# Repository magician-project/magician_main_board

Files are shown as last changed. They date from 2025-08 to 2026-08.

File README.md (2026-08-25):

# Magician Main Board for Sensing Robot

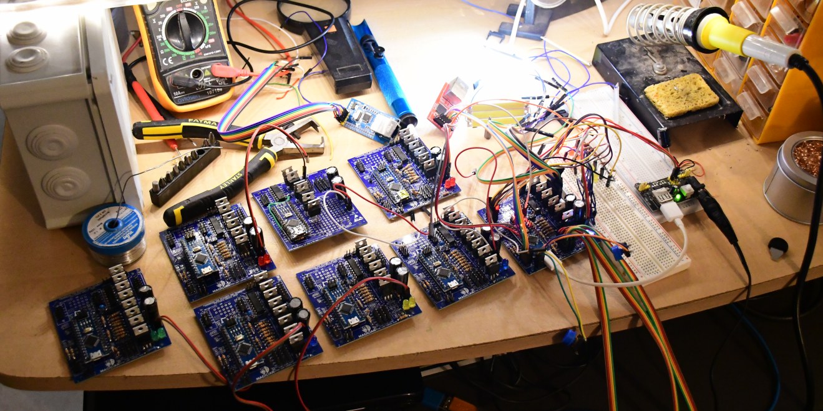
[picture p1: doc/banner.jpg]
8 Protype Assembled PCBs
 

This project implements a **multi-laser distance sensing and light control system** on an **Arduino Nano (ATmega328P)**. 

> This README documents the original [`src/kicad/v1`](src/kicad/v1/README.md) board and its Arduino Nano firmware. The current hardware revision is **MagicianCam4** ([`src/kicad/v4`](src/kicad/v4/README.md)), built around a Raspberry Pi Pico 2 with a VL53L5CX multizone ToF sensor; its firmware lives in [`src/pico2`](src/pico2/).

The software that drives this PCB (along with the Camera/ATI/Teensy) is the [Magician Grabber](https://github.com/magician-project/magician_grabber)

It integrates:

- **3x VL53L0X time-of-flight distance sensors** (over I²C, with unique addresses via XSHUT control) 
- **Up to 8 lights** controlled via direct GPIO or a **74HC595 shift register**
- **Extendable up to 64 lights** by daisy chaining more **74HC595 shift registers**
- **Ethernet W5100 support** (Telnet-style interface) 
- **Two analog input buttons** for manual interaction
- **Serial + Ethernet reporting** of sensor readings, light state, and button presses

The firmware cycles lights automatically, can react to distance sensor readings, and supports both **serial commands** and **Ethernet control**.

---

## Features

- 🔦 **3x VL53L0X** laser distance sensors on a shared I²C bus
- 💡 **6x-8x LED light outputs** (6x direct pin mode or 8x via 74HC595 shift register)
- 🌐 **Ethernet W5100 support** with telnet-style server on port `23`
- 🎛️ **Two analog buttons** (for annotations / input)
- ⚡ **Low-level SRAM monitoring** and reset recovery functions
- 🛠️ **Configurable light modes:**
  - Sequential cycling
  - Pulse mode
  - Sensor-based closest-light decision
  - Timed flashing

---

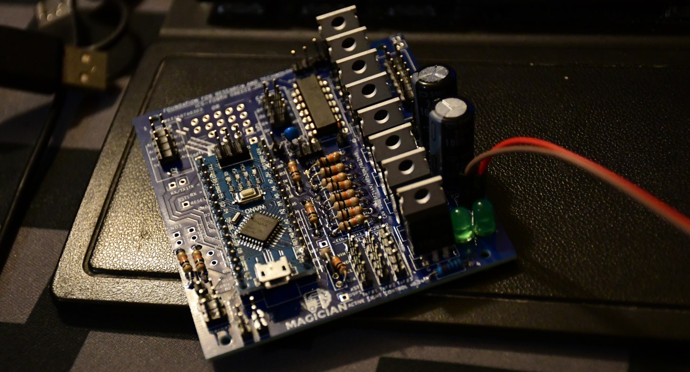
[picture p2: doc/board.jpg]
Magician Main Board close-up
 

## Setup

Important: Before connecting the board, [read the following guide](doc/connectors.md)!

## Hardware Components

- **Arduino Nano with USB-Micro port/ UNO (ATmega328P)**  
- **VL53L0X distance sensors** (x3)  
- **W5100 Ethernet module/shield**  
- **74HC595 shift register** (optional, for light control)  
- **6 LEDs or lights** (controlled by direct pins or shift register)  
- **2 push buttons** (wired to analog inputs `A6` and `A7`)  

### Pin Mapping

| Component | Pin(s) Used | Notes |
|---|---|---|
| I²C (VL53L0X) | A4 (SDA), A5 (SCL) | Shared bus |
| VL53L0X XSHUT (x3) | A0, A1, A2 | Controls sensor reset & addressing |
| Ethernet Reset | D9 | Shared with `I2C_EXTRA_PIN` |
| Direct Light Outputs | D3, D4, D5, D6, D7, D8 | Default pin mode |
| 74HC595 Latch (STCP) | D3 | Used if shift register enabled |
| 74HC595 Clock (SHCP) | D4 | 〃 |
| 74HC595 Data (DS) | D5 | 〃 |
| 74HC595 OE (Enable) | D2 | Active low |
| 74HC595 SRCLR (Clear) | A3 | Active low |
| Buttons | A6, A7 | Analog threshold detection |

---

## Software Setup

1. **Clone this repository** and the Pololu VL53L0X Arduino library:
   ```bash
   git clone https://github.com/YOUR_GITHUB_USERNAME/arduino-nano-vl53l0x-ethernet
   cd arduino-nano-vl53l0x-ethernet
   git clone https://github.com/pololu/vl53l0x-arduino
   cp vl53l0x-arduino/VL53L0X.cpp ./
   cp vl53l0x-arduino/VL53L0X.h ./

    Fix Arduino Nano memory constraints (important!):
    The VL53L0X library is heavy and may cause stack overflow resets.
    To prevent this, reduce the serial buffer sizes:

    Edit:

~/.arduino15/packages/arduino/hardware/avr/1.8.6/cores/arduino/HardwareSerial.h

Change:

    #define SERIAL_TX_BUFFER_SIZE 16
    #define SERIAL_RX_BUFFER_SIZE 8

    With this, the sketch fits:

        Program storage: ~66% used

        Dynamic memory: ~80% used (401 bytes free)

    Install dependencies in Arduino IDE:

        Wire.h (I²C, built-in)

        SPI.h (Ethernet, built-in)

        Ethernet.h (W5100)

    Upload the sketch to your Arduino Nano.

Serial & Ethernet Commands

To connect to Ethernet (assuming you are on the correct subnet)
```
telnet 192.168.137.64
```

To connect using USB/Serial (assuming you are connected over USB)
```
sudo apt install picocom
picocom -b 115200 /dev/ttyUSB0  --imap lfcrlf 
Ctrl + A + Q to exit
```

When connected via USB serial or Ethernet Telnet (port 23), you can control and query the system by supplying the following command bytes.

Command	Description:

| Command                     | Dangerous           | Description |
|-----------------------------|---------------------|-------|
| v              | No    | Print firmware version |
| h              | Yes   | Enable 74HC595 mode + auto light cycling |
| i              | Yes   | Disable 74HC595 (direct pin mode) |
| o              | Maybe | Continuous lights (disable pulsing) |
| p              | Maybe | Switch to pulsing of 500μs / Subsequent calls increase pulse length by 500µs |
| r              | No    | Reset light cycling |
| a              | No    | Enable sensor-based light selection |
| t              | No    | Enable custom cycling mode (mode 3) |
| y              | No    | Flash lights for 10s, then turn off |
| z              | No    | Turn off all lights and reset Arduino |
| 0-6            | Yes   | Manually activate light with number #N |
| +              | Yes   | Step to next light |
| f              | No    | Disable serial/Ethernet reporting |
| x              | No    | (Ethernet only) Print local IP + hardware status | 
| b              | No    | Make Analog Buttons have binary output  1/0 | 
| n              | No    | Make Analog Buttons have non-binary output  0-1024 | 

Commands marked as potentially dangerous directly alter light states that can be dangerous when
using a connected Camera Board that over volts lights. Please see [the setup guide](doc/connectors.md) to understand why. 

Data Reporting

When enabled, the Arduino periodically outputs status lines in CSV format:

<time_ms>,<button1>,<button2>,<distance1>,<distance2>,<distance3>,<light1>,<light2>,...<light6>

Example:

1050,0,1,523,812,1500,1,0,0,0,0,0

    time_ms – system uptime in ms

    button1/button2 – 0 or 1

    distanceN – measured distance in mm (F = failed, H = too high, 0 = inactive)

    lightN – 1 if active, 0 otherwise

Memory & Stability Notes

    Free SRAM is checked at startup; if less than 231 bytes are available, instability is expected.

    Use the reduced VL53L0X library and shrunk serial buffers for stability.

    A resetFunc() software reset is available to recover from low memory conditions.

Versioning

    Version: 0.26

    Major/minor defined in VERSION_MAJOR, VERSION_MINOR.

License

MIT License.
This project uses Pololu’s VL53L0X Arduino Library

Possible Future Improvements

    Add MQTT over Ethernet for IoT integration

    Support ESP32 (more SRAM, WiFi support, no buffer hacks needed)

    Add dynamic light patterns and user-configurable modes

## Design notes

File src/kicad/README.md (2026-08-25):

# KiCad Boards

This directory holds the KiCad projects for the Magician sensing PCBs, organized by hardware revision:

- [`v1/`](v1/README.md) — the original Magician Main Board (Arduino Nano, 3x VL53L0X, 74HC595 shift register). Superseded, kept for reference.
- [`v4/`](v4/README.md) — **MagicianCam4**, the current board (Raspberry Pi Pico 2, VL53L5CX multizone ToF sensor, MCP23018 I/O expander).

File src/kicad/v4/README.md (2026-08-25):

Designed by Giulio Vivo

# MagicianCam4

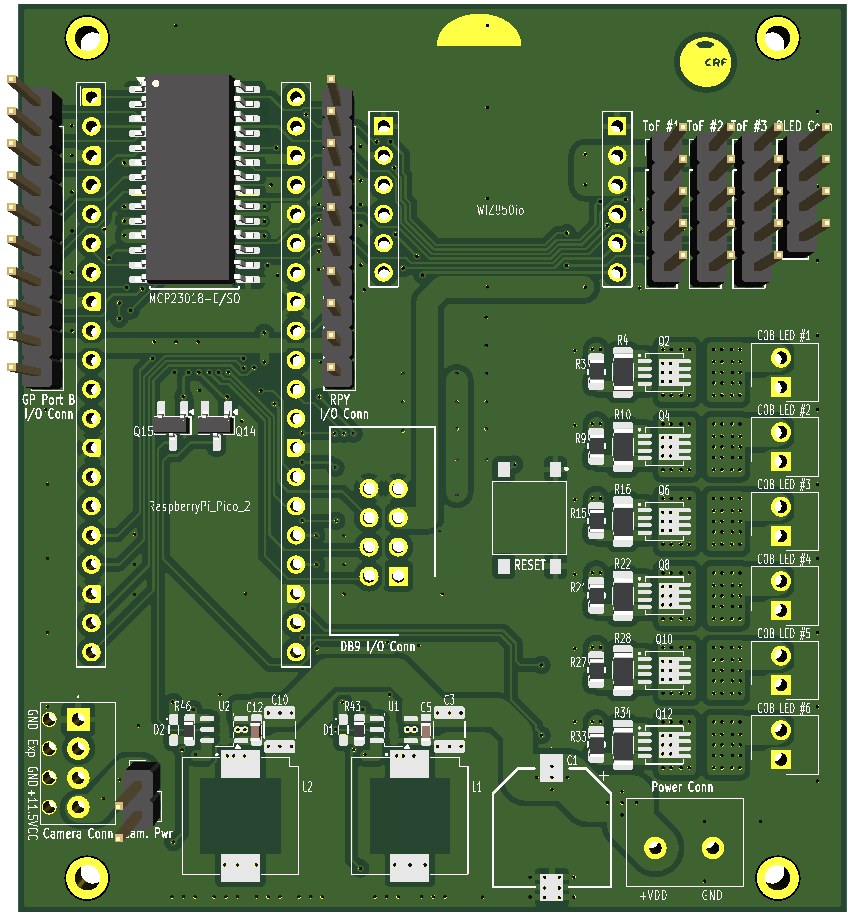
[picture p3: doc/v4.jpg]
MagicianCam4 board


Current revision of the Magician camera/sensing board, built around a **Raspberry Pi Pico 2 (RP2350)** instead of the Arduino Nano used in [`v1/`](../v1/README.md). Firmware lives in [`src/pico2/`](../../pico2/).

Main changes over v1:

- **VL53L5CX multizone ToF sensor** (8x8 = 64 distance zones) replacing the 3x VL53L0X single-zone sensors.
- **MCP23018 I²C I/O expander** for buttons and light control, replacing the 74HC595 shift register chain.
- Exposure-synced LED strobing with per-COB thermal budgeting, since the LED COBs are driven above their rated voltage and rely on strict pulse-width/duty-cycle limits to survive.
- Ethernet connectivity kept compatible with the camera board.

See the MAGICIAN D3.3 deliverable for the background on the sensor/board redesign (split Main + LED-strobe + Ethernet board layout, move from Arduino Mega/Nano to a smaller microcontroller footprint).

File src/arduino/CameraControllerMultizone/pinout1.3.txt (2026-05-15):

MCP23018
Port GPA0 is connected to Push Button 0 (PB0) Input
Port GPA1 is connected to Push Button 1 (PB1) Input
Port GPA2 is connected to ETH Reset pin (Output)
Port GPA3 is connected to XSHUT/laserSwitch port 1 (Output)
Port GPA4 is connected to XSHUT/laserSwitch port 2 (Output)
Port GPA5 is connected to XSHUT/laserSwitch port 3 (Output)
Port GPA6 is connected to A 5V Rail Enable pin (Output) (This will be inverted in 1.4)
Port GPA7 is connected to A 11.5V Rail Enable pin (Output) (This will be inverted in 1.4)

Port GPB0 is connected to nothing
Port GPB1 is connected to nothing 
Port GPB2 is connected to nothing 
Port GPB3 is connected to nothing
Port GPB4 is connected to nothing
Port GPB5 is connected to nothing
Port GPB6 is connected to nothing
Port GPB7 is connected to nothing

The initialization of the MCP23018 must be:
GPA0 is an input button
GPA1 is an input button
GPA2 is an output and should be High
GPA3,GPA4,GPA5 are outputs and should be High
GPA6 is an output should also be High 
GPA7 is an output should also be High

Ports GP4 and GP5 are connected to 3x ToF I2C sensors with initial address 0x52
The address of the MCP23018 is 0x20

The XCG-CP510 Camera is emitting an Active High exposure signal to Port GP2 of the Pico 2

The exposure signal enables a specific light.
Lights are connected in the following way.

Light 1 is connected to GP6
Light 2 is connected to GP7
Light 3 is connected to GP8
Light 4 is connected to GP9
Light 5 is connected to GP10
Light 6 is connected to GP11

The ethernet (W5500 USR-ES1)
is connected in the following way:
MISO is connected to GP16 of the Pico2
MOSI is connected to GP19 of the Pico2
SCCLK is connected to GP18 of the Pico2
SCN is connected to GP17 of the Pico2
INT is connected to GP22 of the Pico2
RST is connected to GPA2 of the MCP23018

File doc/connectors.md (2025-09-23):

# Magician Main Board Connections

Due to Magician being a research project (with a pending cascade round) and hardware being very difficult to upgrade there has been an effort to make the Magician Main board 
as expandable as possible, supporting a variety of operation modes using the same hardware.

When connecting the main board with the rest of the system, one must always keep in mind:
1) What is the LED COB lights rated voltage
2) Is the LED COB Light Output connected to the Main Board OR the Camera Board ?
3) What is the LED Voltage input and where it is connected (Main Board OR Camera Board) 

## Main Board and Camera Board Connections overview

There are 2x boards, the Main Board and the Camera Board.

The Main Board looks like this and features the following connectors.

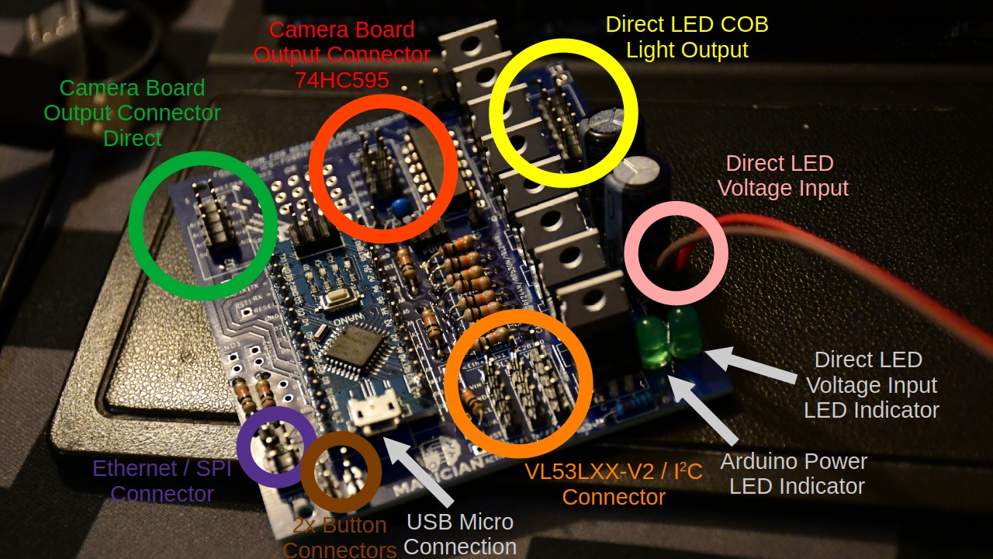
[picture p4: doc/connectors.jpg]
Magician Main Board PCB Connectors
 

The Camera Board looks like this and features the following connectors.

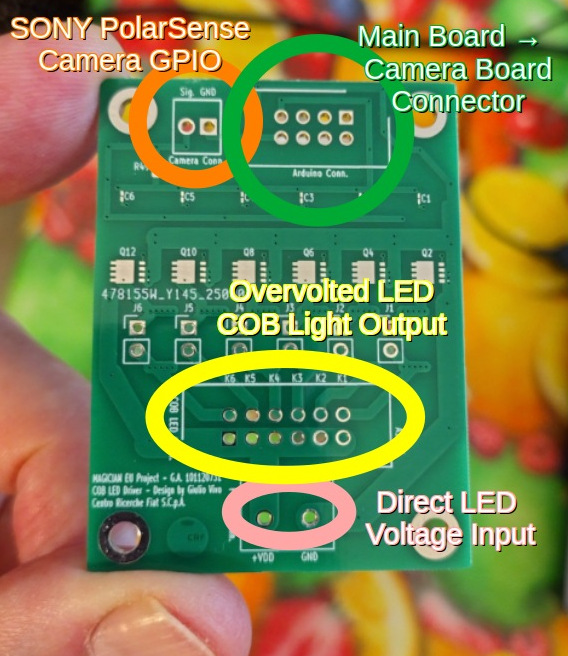
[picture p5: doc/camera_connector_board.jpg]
Magician Camera Board PCB Connectors
 

## Main Board Setup Scenarios

If you want to use regular non-overvolted lights and S/W Sync of lights to the Camera:

1) You do not need the Camera Board!
2) Connect the LED COBs to the (YELLOW Top Right) Direct LED COB Light output.
3) Connect the 3.3V LED COB input on the Direct LED Voltage Input (PINK color) of the Main Board
4) Start the Magician Mainboard by sending an "h" byte 

If you want to use LED overvolting and H/W Sync of lights to the Camera:

0) Since you are overvolting the LEDS past their factory specs you need to be VERY careful what you do!
1) Connect the Camera Board to the Magician Main Board using a cable that ties the GREEN headers ( on both images above ).
2) Connect the LED COBs to the Overvolted LED COB Light output of the Camera Board.
3) Connect the Overvolted LED COB input voltage on the Direct LED Voltage Input (PINK color) of the Camera Board
4) Start the Magician Mainboard by sending an "i" byte (this is the default behavior for safety reasons)

## Closer look on the PCBs and Diagrams

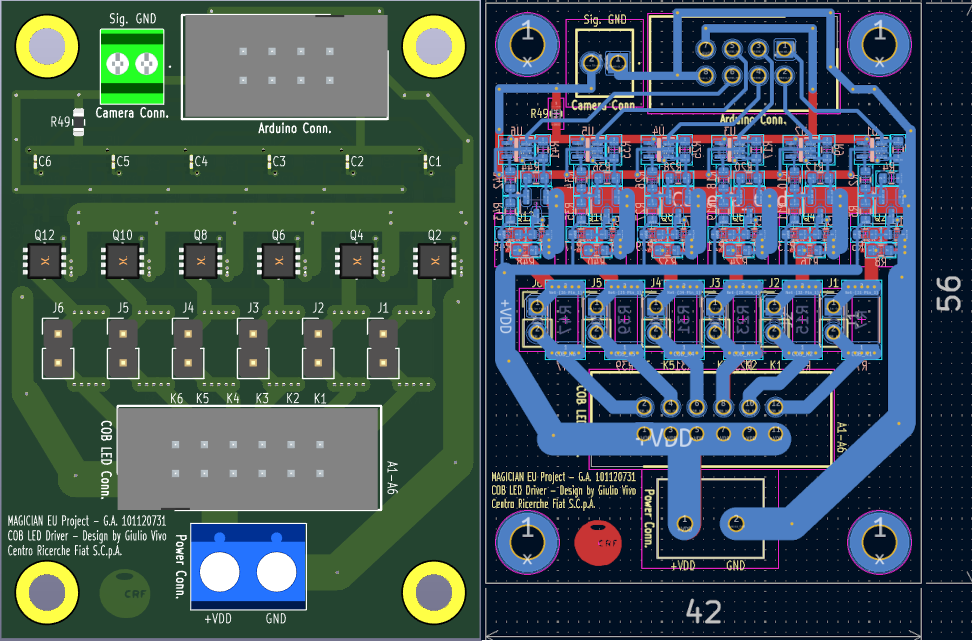
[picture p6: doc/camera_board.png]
Magician Camera Board PCB Connectors
 

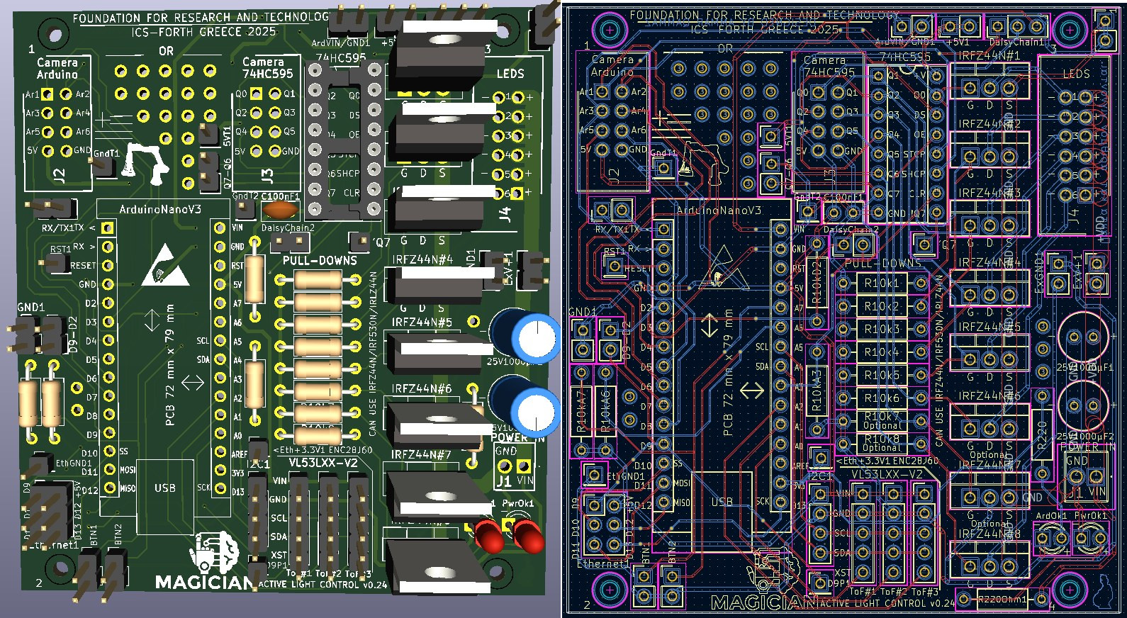
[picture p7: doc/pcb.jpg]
Magician Main Board close-up
 

## Connecting Ethernet support using a W5100

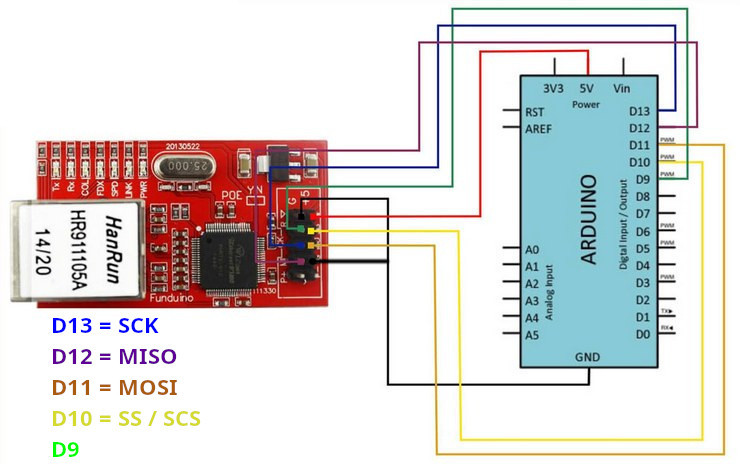
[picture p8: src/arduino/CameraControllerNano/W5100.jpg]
W5100 Ethernet SPI chip


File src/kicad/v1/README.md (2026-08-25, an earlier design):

# Magician Main Board (v1)

Original Magician Main Board PCB, designed around an **Arduino Nano (ATmega328P)** with 3x VL53L0X time-of-flight distance sensors and up to 64 lights driven through daisy-chained 74HC595 shift registers, per the [top-level README](../../../README.md).

This is the board described in the MAGICIAN D3.3 deliverable as replacing the earlier breadboard harness for the V2 camera sensor. It has been moved here from `src/kicad/` and superseded by [`v4/`](../v4/README.md) (MagicianCam4), which moves to a Raspberry Pi Pico 2 and a VL53L5CX multizone ToF sensor. Kept for reference and for any deployments still running this hardware revision.

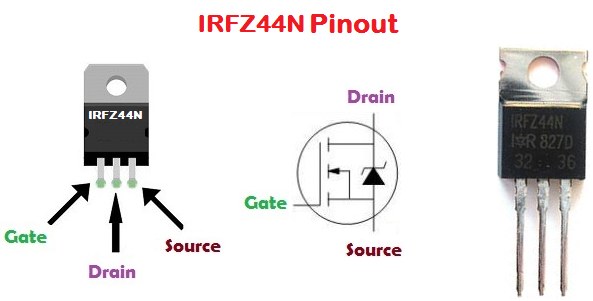
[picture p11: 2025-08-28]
src/arduino/CameraControllerNano/irfz44n.jpg

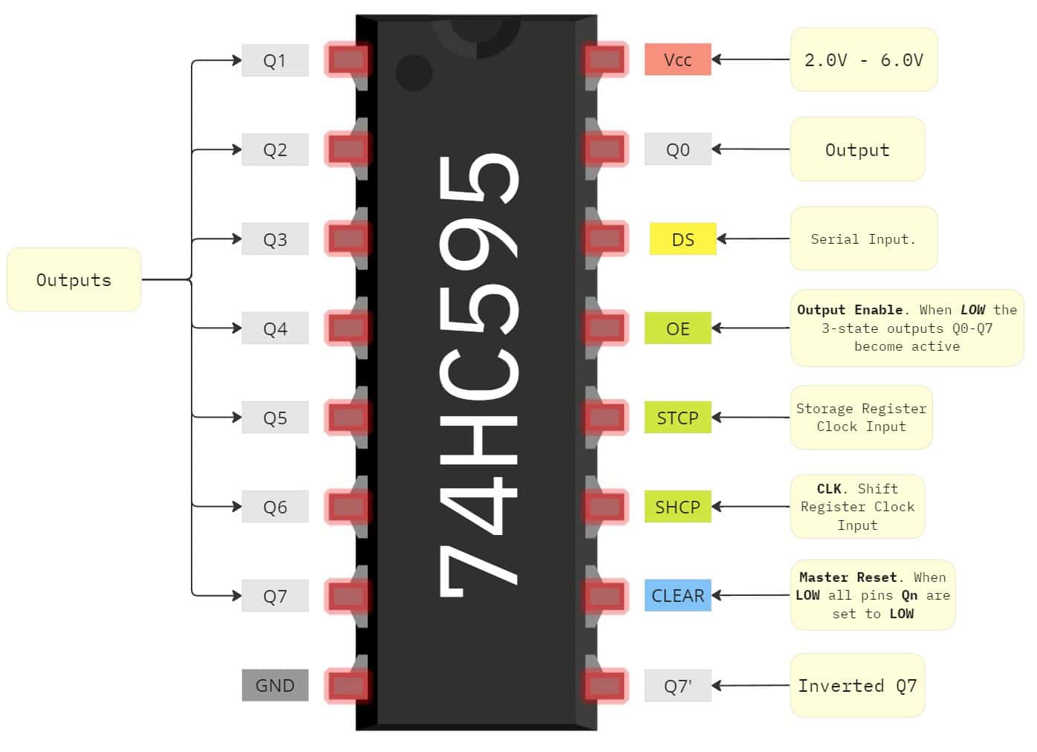
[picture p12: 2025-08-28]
src/arduino/CameraControllerNano/74HC595.jpg

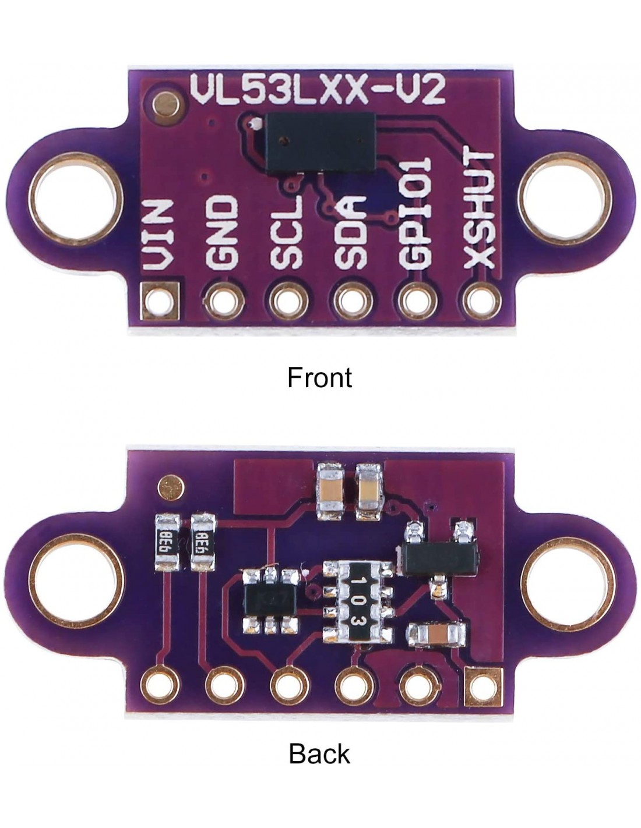
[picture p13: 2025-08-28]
src/arduino/CameraControllerNano/vl53lxx-v2.jpg

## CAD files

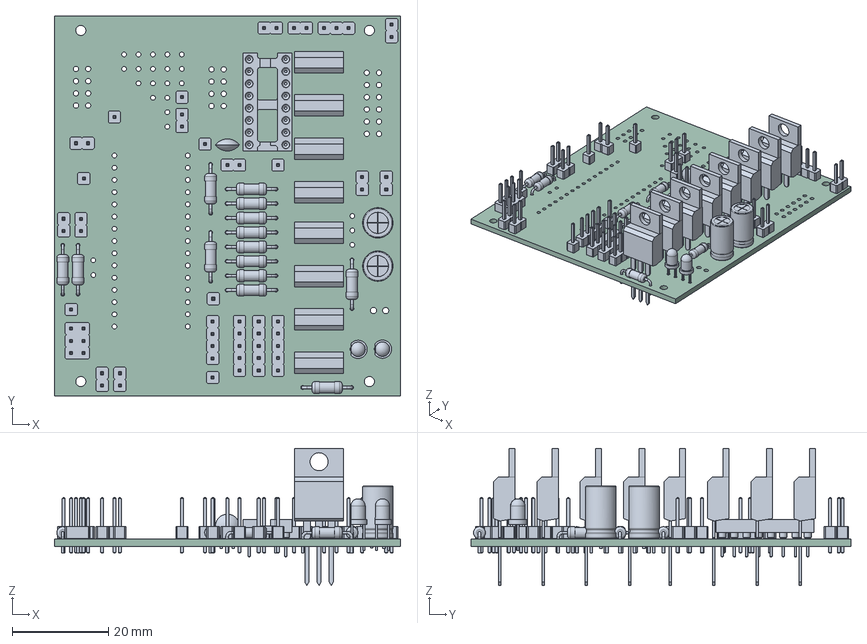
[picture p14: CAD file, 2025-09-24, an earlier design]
src/kicad/v1/magician_main_board.step
72.0 x 79.0 x 28.5 mm
PinHeader_1x05_P2.54mm_Vertical x 3
R_Axial_DIN0207_L6.3mm_D2.5mm_P10.16mm_Horizontal x 14
PinHeader_1x02_P2.54mm_Vertical x 12
TO-220-3_Vertical x 8
LED_D3.0mm x 2
PinHeader_1x01_P2.54mm_Vertical x 7
C_Radial_D6.3mm_H11.0mm_P2.50mm x 2
DIP-16_W7.62mm_Socket
PinHeader_2x03_P2.54mm_Vertical
C_Disc_D5.0mm_W2.5mm_P2.50mm
PinHeader_1x03_P2.54mm_Vertical
PinHeader_1x04_P2.54mm_Vertical
magician_main_board_PCB

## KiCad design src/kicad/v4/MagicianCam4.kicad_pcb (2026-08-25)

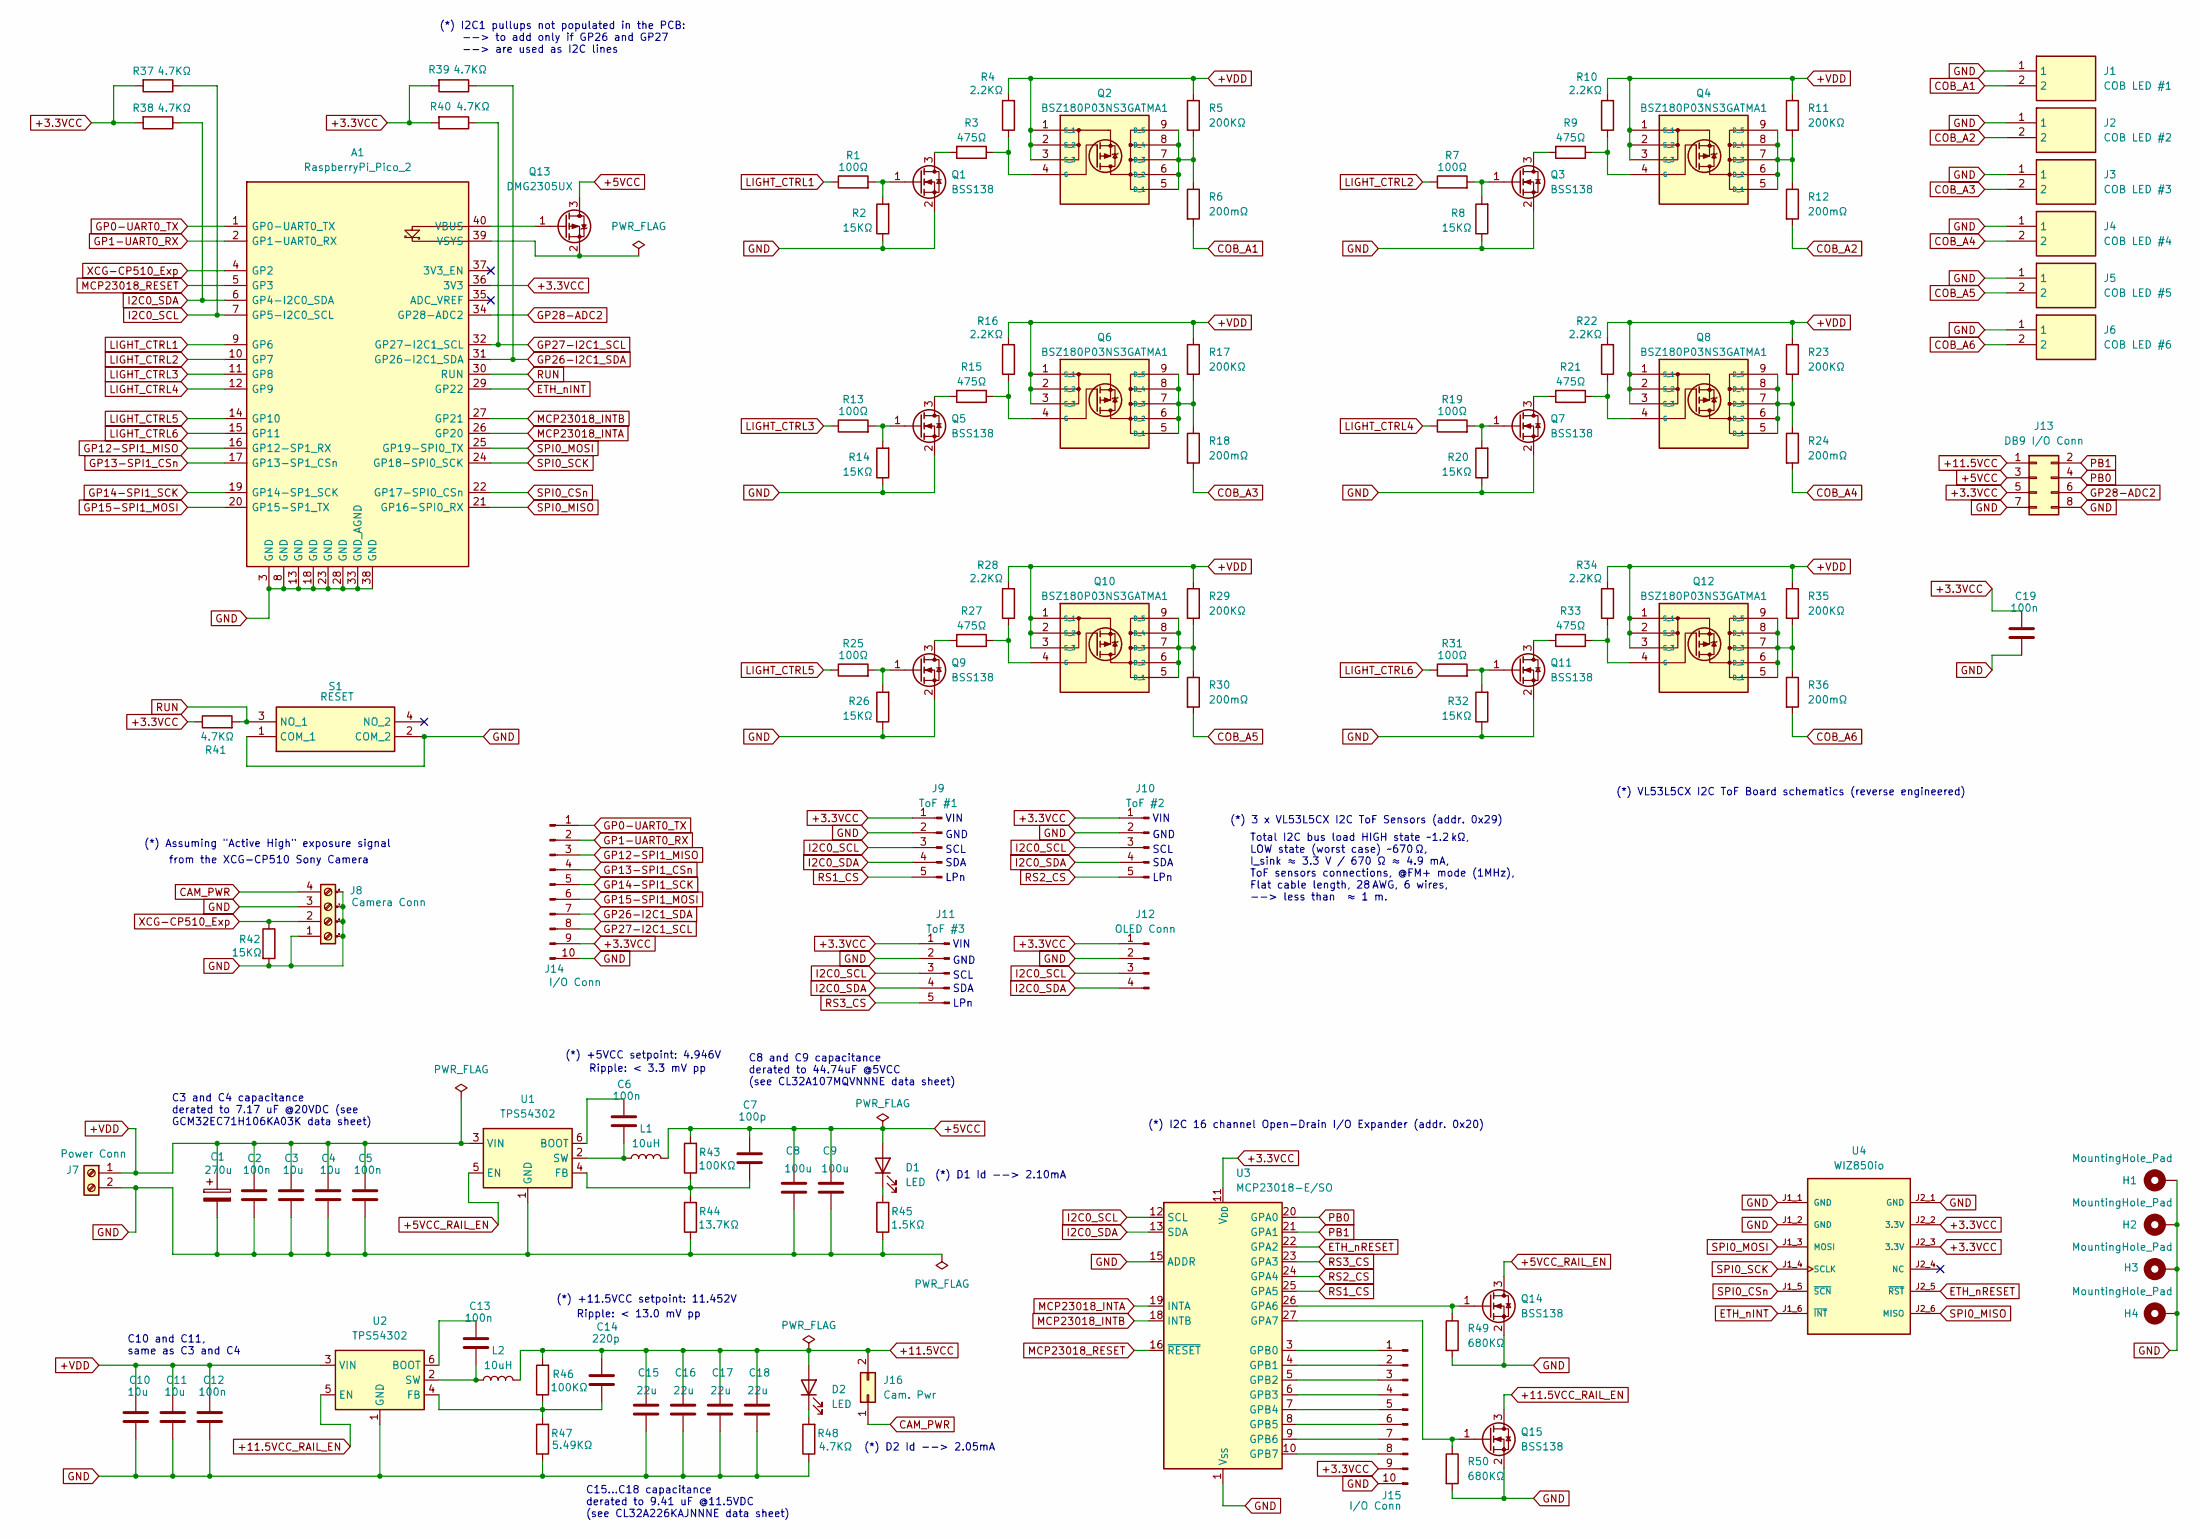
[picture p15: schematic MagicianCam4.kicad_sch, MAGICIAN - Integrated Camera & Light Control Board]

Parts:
A1: RaspberryPi_Pico_2; RaspberryPi_Pico_THT
C1: 270u; EEHZS1H221P
C2, C5, C12, C19: 100n; C_0603_1608Metric_HANDSOLD
C3, C4, C10, C11: 10u; GCM32EC71H106KA03K
C6, C13: 100n; C_0805_2012Metric__HANDSOLD
C7: 100p; C_0603_1608Metric_HANDSOLD
C8, C9: 100u; CL32A107MQVNNNE
C14: 220p; C_0603_1608Metric_HANDSOLD
C15, C16, C17, C18: 22u; CL32A226KAJNNNE
D1, D2: LED; LSQ97601N1Q21
H1, H2, H3, H4: MountingHole_Pad; MountingHole_2.2mm_M2_DIN965_Pad
J1: COB LED #1; 640456-2; Manufacturer_Part_Number 640456-2
J2: COB LED #2; 640456-2; Manufacturer_Part_Number 640456-2
J3: COB LED #3; 640456-2; Manufacturer_Part_Number 640456-2
J4: COB LED #4; 640456-2; Manufacturer_Part_Number 640456-2
J5: COB LED #5; 640456-2; Manufacturer_Part_Number 640456-2
J6: COB LED #6; 640456-2; Manufacturer_Part_Number 640456-2
J7: Power Conn; TC0203620000G
J8: Camera Conn; RS 790-1102
J9: ToF #1; PinHeader_1x05_P2.54mm_Vertical
J10: ToF #2; PinHeader_1x05_P2.54mm_Vertical
J11: ToF #3; PinHeader_1x05_P2.54mm_Vertical
J12: OLED Conn; PinHeader_1x04_P2.54mm_Vertical
J13: DB9 I/O Conn; T821108A1S100CEU
J14, J15: I/O Conn; PinHeader_1x10_P2.54mm_Vertical
J16: Cam. Pwr; PinHeader_1x02_P2.54mm_Vertical
L1, L2: 10uH; SLF10165
Q1, Q3, Q5, Q7, Q9, Q11, Q14, Q15: BSS138; SOT-23_HANDSOLD2
Q2, Q4, Q6, Q8, Q10, Q12: BSZ180P03NS3GATMA1
Q13: DMG2305UX; SOT-23_HANDSOLD2
R1, R7, R13, R19, R25, R31: 100Ω; R_0603_1608Metric_HANDSOLD
R2, R8, R14, R20, R26, R32, R42: 15KΩ; R_0603_1608Metric_HANDSOLD
R3, R9, R15, R21, R27, R33: 475Ω; R_0805_2012Metric_Pad1.20x1.40mm_HandSolder
R4, R10, R16, R22, R28, R34: 2.2KΩ; R_1206_3216Metric_Pad1.30x1.75mm_HandSolder
R5, R11, R17, R23, R29, R35: 200KΩ; R_0603_1608Metric_HANDSOLD
R6, R12, R18, R24, R30, R36: 200mΩ; R_2512_6332Metric_Pad1.40x3.35mm_HandSolder
R37, R38, R48: 4.7KΩ; R_0603_1608Metric_HANDSOLD
R39, R40, R41: 4.7KΩ; R_0603_1608Metric
R43, R46: 100KΩ; R_0603_1608Metric_HANDSOLD
R44: 13.7KΩ; R_0603_1608Metric_HANDSOLD
R45: 1.5KΩ; R_0603_1608Metric_HANDSOLD
R47: 5.49KΩ; R_0603_1608Metric_HANDSOLD
R49, R50: 680KΩ; R_0603_1608Metric_HANDSOLD
S1: RESET; PTS641SM25SMTR2LFS; Manufacturer_Part_Number PTS641 SM25 SMTR2 LFS
U1, U2: TPS54302; SOT-23-THIN-6_HANDSOLD
U3: MCP23018-E/SO; SOIC-28W_7.5x17.9mm_P1.27mm
U4: WIZ850io; WIZ850IO; PARTREV V1.0

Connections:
+3.3VCC: A1.36 (3V3), C19.1, J9.1, J10.1, J11.1, J12.1, J13.5, J14.9, J15.9, R37.2, R38.2, R39.2, R40.2, R41.1, U3.11 (V_{DD}), U4.J2_2 (3.3V), U4.J2_3 (3.3V)
+5VCC: C7.1, C8.1, C9.1, D1.2 (A), J13.3, L1.2, Q13.3 (D), R43.2
+5VCC_RAIL_EN: Q14.3 (D), U1.5 (EN)
+11.5VCC: C14.1, C15.1, C16.1, C17.1, C18.1, D2.2 (A), J13.1, J16.2, L2.2, R46.2
+11.5VCC_RAIL_EN: Q15.3 (D), U2.5 (EN)
+VDD: C1.1, C2.1, C3.1, C4.1, C5.1, C10.1, C11.1, C12.1, J7.1, Q2.1 (S_1), Q2.2 (S_2), Q2.3 (S_3), Q4.1 (S_1), Q4.2 (S_2), Q4.3 (S_3), Q6.1 (S_1), Q6.2 (S_2), Q6.3 (S_3), Q8.1 (S_1), Q8.2 (S_2), Q8.3 (S_3), Q10.1 (S_1), Q10.2 (S_2), Q10.3 (S_3), Q12.1 (S_1), Q12.2 (S_2), Q12.3 (S_3), R4.2, R5.1, R10.2, R11.1, R16.2, R17.1, R22.2, R23.1, R28.2, R29.1, R34.2, R35.1, U1.3 (VIN), U2.3 (VIN)
CAM_PWR: J8.4, J16.1
COB_A1: J1.2, R6.2
COB_A2: J2.2, R12.2
COB_A3: J3.2, R18.2
COB_A4: J4.2, R24.2
COB_A5: J5.2, R30.2
COB_A6: J6.2, R36.2
ETH_nINT: A1.29 (GP22), U4.J1_6 (~INT)
ETH_nRESET: U3.22 (GPA2), U4.J2_5 (~RST)
GND: A1.3 (GND), A1.8 (GND), A1.13 (GND), A1.18 (GND), A1.23 (GND), A1.28 (GND), A1.33 (GND_AGND), A1.38 (GND), C1.2, C2.2, C3.2, C4.2, C5.2, C8.2, C9.2, C10.2, C11.2, C12.2, C15.2, C16.2, C17.2, C18.2, C19.2, H1.1 (1_1), H2.1 (1_1), H3.1 (1_1), H4.1 (1_1), J1.1, J2.1, J3.1, J4.1, J5.1, J6.1, J7.2, J8.1, J8.3, J8.5 (Pin_1), J8.6 (Pin_1), J8.7 (Pin_1), J8.8 (Pin_1), J9.2, J10.2, J11.2, J12.2, J13.7, J13.8, J14.10, J15.10, Q1.2 (S), Q3.2 (S), Q5.2 (S), Q7.2 (S), Q9.2 (S), Q11.2 (S), Q14.2 (S), Q15.2 (S), R2.1, R8.1, R14.1, R20.1, R26.1, R32.1, R42.2, R44.1, R45.1, R47.1, R48.1, R49.2, R50.2, S1.1 (COM_1), S1.2 (COM_2), U1.1 (GND), U2.1 (GND), U3.1 (V_{SS}), U3.15 (ADDR), U4.J1_1 (GND), U4.J1_2 (GND), U4.J2_1 (GND)
GP0-UART0_TX: A1.1 (GP0-UART0_TX), J14.1
GP1-UART0_RX: A1.2 (GP1-UART0_RX), J14.2
GP12-SPI1_MISO: A1.16 (GP12-SP1_RX), J14.3
GP13-SPI1_CSn: A1.17 (GP13-SP1_CSn), J14.4
GP14-SPI1_SCK: A1.19 (GP14-SP1_SCK), J14.5
GP15-SPI1_MOSI: A1.20 (GP15-SP1_TX), J14.6
GP26-I2C1_SDA: A1.31 (GP26-I2C1_SDA), J14.7, R39.1
GP27-I2C1_SCL: A1.32 (GP27-I2C1_SCL), J14.8, R40.1
GP28-ADC2: A1.34 (GP28-ADC2), J13.6
I2C0_SCL: A1.7 (GP5-I2C0_SCL), J9.3, J10.3, J11.3, J12.3, R37.1, U3.12 (SCL)
I2C0_SDA: A1.6 (GP4-I2C0_SDA), J9.4, J10.4, J11.4, J12.4, R38.1, U3.13 (SDA)
LIGHT_CTRL1: A1.9 (GP6), R1.1
LIGHT_CTRL2: A1.10 (GP7), R7.1
LIGHT_CTRL3: A1.11 (GP8), R13.1
LIGHT_CTRL4: A1.12 (GP9), R19.1
LIGHT_CTRL5: A1.14 (GP10), R25.1
LIGHT_CTRL6: A1.15 (GP11), R31.1
MCP23018_INTA: A1.26 (GP20), U3.19 (INTA)
MCP23018_INTB: A1.27 (GP21), U3.18 (INTB)
MCP23018_RESET: A1.5 (GP3), U3.16 (~RESET)
unnamed: A1.40 (VBUS), Q13.1 (G)
unnamed: A1.39 (VSYS), Q13.2 (S)
unnamed: D1.1 (K), R45.2
unnamed: D2.1 (K), R48.2
unnamed: J15.1, U3.3 (GPB0)
unnamed: J15.2, U3.4 (GPB1)
unnamed: J15.3, U3.5 (GPB2)
unnamed: J15.4, U3.6 (GPB3)
unnamed: J15.5, U3.7 (GPB4)
unnamed: J15.6, U3.8 (GPB5)
unnamed: J15.7, U3.9 (GPB6)
unnamed: J15.8, U3.10 (GPB7)
unnamed: Q1.3 (D), R3.2
unnamed: Q1.1 (G), R1.2, R2.2
unnamed: Q2.5 (D_1), Q2.6 (D_2), Q2.7 (D_3), Q2.8 (D_4), Q2.9 (D_5), R5.2, R6.1
unnamed: Q2.4 (G), R3.1, R4.1
unnamed: Q3.3 (D), R9.2
unnamed: Q3.1 (G), R7.2, R8.2
unnamed: Q4.5 (D_1), Q4.6 (D_2), Q4.7 (D_3), Q4.8 (D_4), Q4.9 (D_5), R11.2, R12.1
unnamed: Q4.4 (G), R9.1, R10.1
unnamed: Q5.3 (D), R15.2
unnamed: Q5.1 (G), R13.2, R14.2
unnamed: Q6.5 (D_1), Q6.6 (D_2), Q6.7 (D_3), Q6.8 (D_4), Q6.9 (D_5), R17.2, R18.1
unnamed: Q6.4 (G), R15.1, R16.1
unnamed: Q7.3 (D), R21.2
unnamed: Q7.1 (G), R19.2, R20.2
unnamed: Q8.5 (D_1), Q8.6 (D_2), Q8.7 (D_3), Q8.8 (D_4), Q8.9 (D_5), R23.2, R24.1
unnamed: Q8.4 (G), R21.1, R22.1
unnamed: Q9.3 (D), R27.2
unnamed: Q9.1 (G), R25.2, R26.2
unnamed: Q10.5 (D_1), Q10.6 (D_2), Q10.7 (D_3), Q10.8 (D_4), Q10.9 (D_5), R29.2, R30.1
unnamed: Q10.4 (G), R27.1, R28.1
unnamed: Q11.3 (D), R33.2
unnamed: Q11.1 (G), R31.2, R32.2
unnamed: Q12.5 (D_1), Q12.6 (D_2), Q12.7 (D_3), Q12.8 (D_4), Q12.9 (D_5), R35.2, R36.1
unnamed: Q12.4 (G), R33.1, R34.1
unnamed: Q14.1 (G), R49.1, U3.26 (GPA6)
unnamed: Q15.1 (G), R50.1, U3.27 (GPA7)
unnamed: C6.1, U1.6 (BOOT)
unnamed: C7.2, R43.1, R44.2, U1.4 (FB)
unnamed: C6.2, L1.1, U1.2 (SW)
unnamed: C13.1, U2.6 (BOOT)
unnamed: C14.2, R46.1, R47.2, U2.4 (FB)
unnamed: C13.2, L2.1, U2.2 (SW)
PB0: J13.4, U3.20 (GPA0)
PB1: J13.2, U3.21 (GPA1)
RS1_CS: J9.5, U3.25 (GPA5)
RS2_CS: J10.5, U3.24 (GPA4)
RS3_CS: J11.5, U3.23 (GPA3)
RUN: A1.30 (RUN), R41.2, S1.3 (NO_1)
SPI0_CSn: A1.22 (GP17-SPI0_CSn), U4.J1_5 (~SCN)
SPI0_MISO: A1.21 (GP16-SPI0_RX), U4.J2_6 (MISO)
SPI0_MOSI: A1.25 (GP19-SPI0_TX), U4.J1_3 (MOSI)
SPI0_SCK: A1.24 (GP18-SPI0_SCK), U4.J1_4 (SCLK)
XCG-CP510_Exp: A1.4 (GP2), J8.2, R42.1

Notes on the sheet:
from the XCG-CP510 Sony Camera
LPn
Ripple: < 13.0 mV pp
(*) +5VCC setpoint: 4.946V
(*) I2C 16 channel Open-Drain I/O Expander (addr. 0x20)
C3 and C4 capacitance derated to 7.17 uF @20VDC (see GCM32EC71H106KA03K data sheet)
Total I2C bus load HIGH state ~1.2 kΩ, LOW state (worst case) ~670 Ω, I_sink ≈ 3.3 V / 670 Ω ≈ 4.9 mA, ToF sensors connections, @FM+ mode (1MHz), Flat cable length, 28 AWG, 6 wires, --> less than ≈ 1 m.
VIN
GND
SDA
C8 and C9 capacitance derated to 44.74uF @5VCC (see CL32A107MQVNNNE data sheet)
SCL
C15...C18 capacitance derated to 9.41 uF @11.5VDC (see CL32A226KAJNNNE data sheet)
(*) D2 Id --> 2.05mA
C10 and C11, same as C3 and C4
(*) D1 Id --> 2.10mA
(*) VL53L5CX I2C ToF Board schematics (reverse engineered)
(*) Assuming "Active High" exposure signal
Ripple: < 3.3 mV pp
(*) 3 x VL53L5CX I2C ToF Sensors (addr. 0x29)
(*) I2C1 pullups not populated in the PCB: --> to add only if GP26 and GP27 --> are used as I2C lines
(*) +11.5VCC setpoint: 11.452V

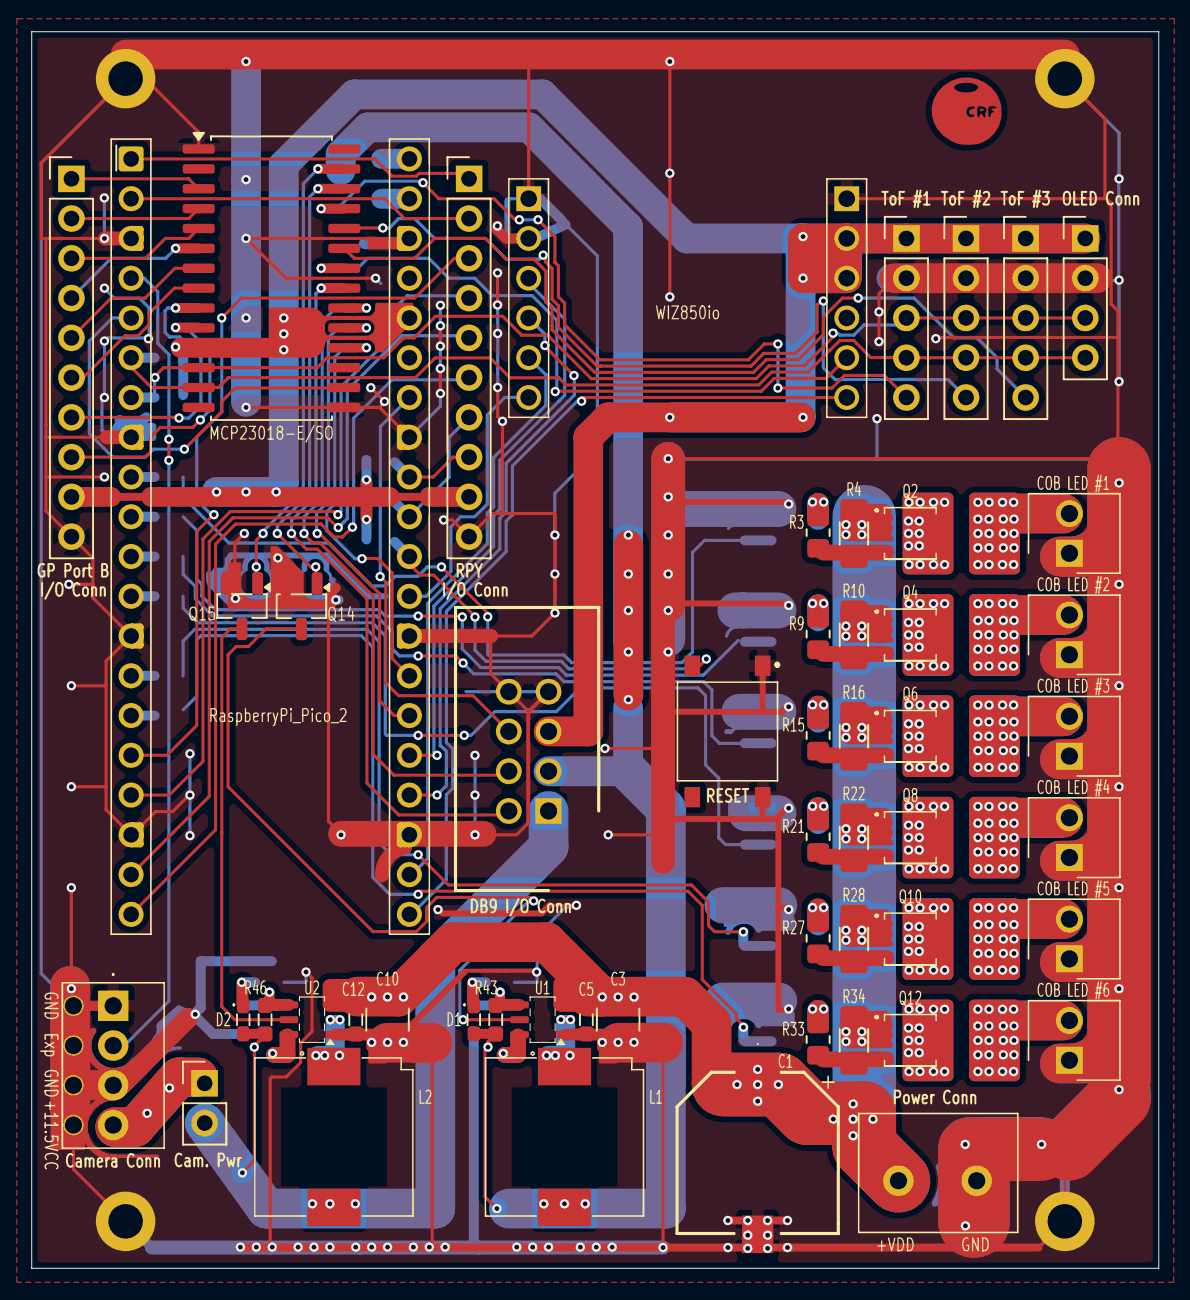
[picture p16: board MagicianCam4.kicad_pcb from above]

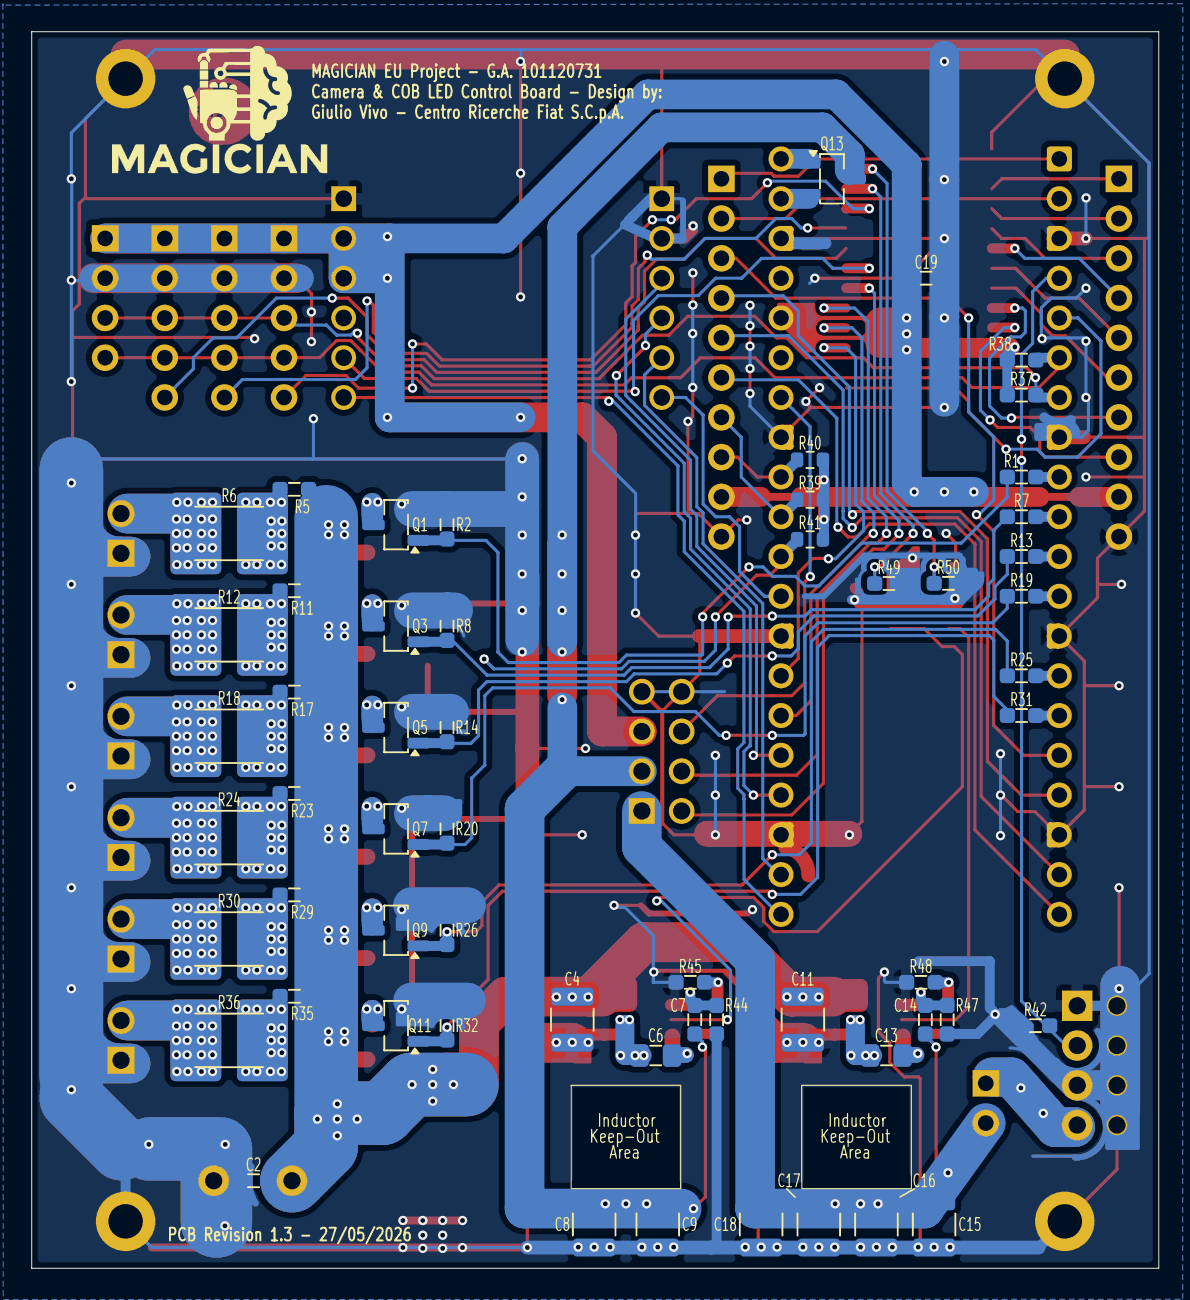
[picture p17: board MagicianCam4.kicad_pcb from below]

Board: 2 copper layers, 72.0 x 79.0 mm, 114 parts (57 on the bottom side), 91 nets.

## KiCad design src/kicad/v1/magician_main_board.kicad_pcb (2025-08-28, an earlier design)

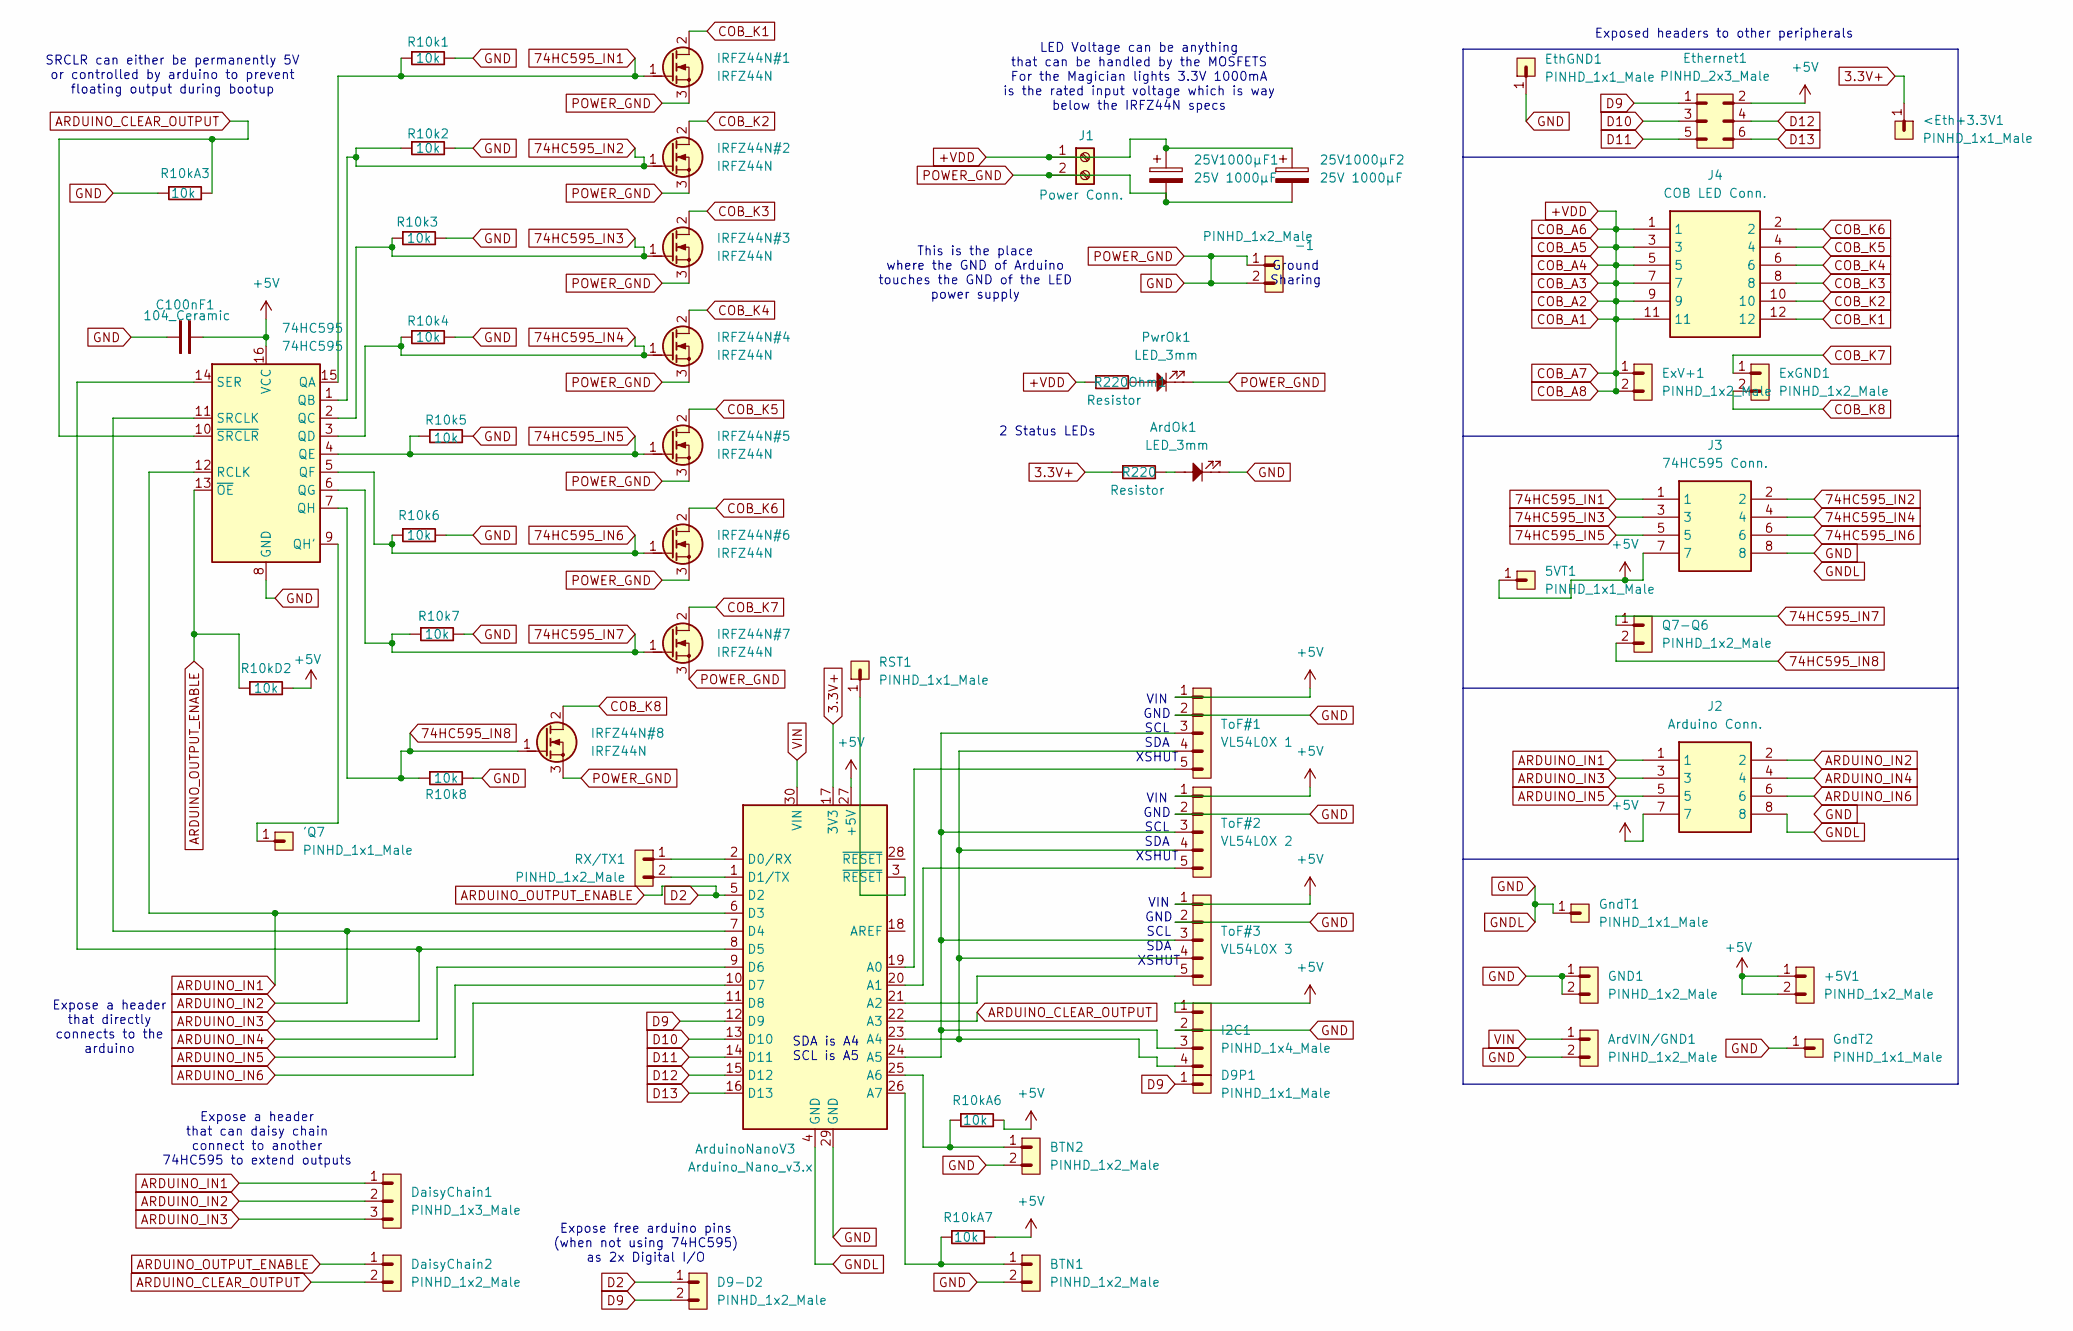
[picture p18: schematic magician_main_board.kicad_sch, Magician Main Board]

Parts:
5VT1: PINHD_1x1_Male; PinHeader_1x01_P2.54mm_Vertical
25V1000μF1, 25V1000μF2: 25V 1000μF; C_Radial_D6.3mm_H11.0mm_P2.50mm
74HC595: 74HC595; DIP-16_W7.62mm_Socket
'Q7: PINHD_1x1_Male; PinHeader_1x01_P2.54mm_Vertical
+5V1: PINHD_1x2_Male; PinHeader_1x02_P2.54mm_Vertical
-1: PINHD_1x2_Male; PinHeader_1x02_P2.54mm_Vertical
<Eth+3.3V1: PINHD_1x1_Male; PinHeader_1x01_P2.54mm_Vertical
ArdOk1: LED_3mm; LED_D3.0mm
ArdVIN/GND1: PINHD_1x2_Male; PinHeader_1x02_P2.54mm_Vertical
ArduinoNanoV3: Arduino_Nano_v3.x; Arduino_Nano
BTN1, BTN2: PINHD_1x2_Male; PinHeader_1x02_P2.54mm_Vertical
C100nF1: 104_Ceramic; C_Disc_D5.0mm_W2.5mm_P2.50mm
D9-D2: PINHD_1x2_Male; PinHeader_1x02_P2.54mm_Vertical
D9P1: PINHD_1x1_Male; PinHeader_1x01_P2.54mm_Vertical
DaisyChain1: PINHD_1x3_Male; PinHeader_1x03_P2.54mm_Vertical
DaisyChain2: PINHD_1x2_Male; PinHeader_1x02_P2.54mm_Vertical
EthGND1: PINHD_1x1_Male; PinHeader_1x01_P2.54mm_Vertical
Ethernet1: PINHD_2x3_Male; PinHeader_2x03_P2.54mm_Vertical
ExGND1: PINHD_1x2_Male; PinHeader_1x02_P2.54mm_Vertical
ExV+1: PINHD_1x2_Male; PinHeader_1x02_P2.54mm_Vertical
GND1: PINHD_1x2_Male; PinHeader_1x02_P2.54mm_Vertical
GndT1, GndT2: PINHD_1x1_Male; PinHeader_1x01_P2.54mm_Vertical
I2C1: PINHD_1x4_Male; PinHeader_1x04_P2.54mm_Vertical
IRFZ44N#1, IRFZ44N#2, IRFZ44N#3, IRFZ44N#4, IRFZ44N#5, IRFZ44N#6, IRFZ44N#7, IRFZ44N#8: IRFZ44N; TO-220-3_Vertical_GDS
J1: Power Conn.; 691210910002
J2: Arduino Conn.; T821108A1S100CEU; Manufacturer_Part_Number T821108A1S100CEU; Mouser Part Number N/A
J3: 74HC595 Conn.; T821108A1S100CEU; Manufacturer_Part_Number T821108A1S100CEU; Mouser Part Number N/A
J4: COB LED Conn.; T821112A1S100CEU; Manufacturer_Part_Number T821112A1S100CEU; Mouser Part Number N/A
PwrOk1: LED_3mm; LED_D3.0mm
Q7-Q6: PINHD_1x2_Male; PinHeader_1x02_P2.54mm_Vertical
R10k1, R10k2, R10k3, R10k4, R10k5, R10k6, R10k7, R10k8, R10kA3, R10kA6, R10kA7, R10kD2: 10k; R_Axial_DIN0207_L6.3mm_D2.5mm_P10.16mm_Horizontal
R220, R220Ohm1: Resistor; R_Axial_DIN0207_L6.3mm_D2.5mm_P10.16mm_Horizontal
RST1: PINHD_1x1_Male; PinHeader_1x01_P2.54mm_Vertical
RX/TX1: PINHD_1x2_Male; PinHeader_1x02_P2.54mm_Vertical
ToF#1: VL54L0X 1; PinHeader_1x05_P2.54mm_Vertical
ToF#2: VL54L0X 2; PinHeader_1x05_P2.54mm_Vertical
ToF#3: VL54L0X 3; PinHeader_1x05_P2.54mm_Vertical

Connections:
3.3V+: <Eth+3.3V1.1, ArduinoNanoV3.17 (3V3), R220.1
74HC595_IN1: 74HC595.15 (QA), IRFZ44N#1.1 (G), J3.1, R10k1.1
74HC595_IN2: 74HC595.1 (QB), IRFZ44N#2.1 (G), J3.2, R10k2.1
74HC595_IN3: 74HC595.2 (QC), IRFZ44N#3.1 (G), J3.3, R10k3.1
74HC595_IN4: 74HC595.3 (QD), IRFZ44N#4.1 (G), J3.4, R10k4.1
74HC595_IN5: 74HC595.4 (QE), IRFZ44N#5.1 (G), J3.5, R10k5.1
74HC595_IN6: 74HC595.5 (QF), IRFZ44N#6.1 (G), J3.6, R10k6.1
74HC595_IN7: 74HC595.6 (QG), IRFZ44N#7.1 (G), Q7-Q6.1, R10k7.1
74HC595_IN8: 74HC595.7 (QH), IRFZ44N#8.1 (G), Q7-Q6.2, R10k8.1
+5V: 5VT1.1, 74HC595.16 (VCC), +5V1.1, +5V1.2, ArduinoNanoV3.27 (+5V), C100nF1.2, Ethernet1.2, I2C1.1, J2.7, J3.7, R10kA6.2, R10kA7.2, R10kD2.2, ToF#1.1, ToF#2.1, ToF#3.1
+VDD: 25V1000μF1.1, 25V1000μF2.1, ExV+1.1, ExV+1.2, J1.1, J4.1, J4.3, J4.5, J4.7, J4.9, J4.11, R220Ohm1.1
ARDUINO_CLEAR_OUTPUT: 74HC595.10 (~SRCLR), ArduinoNanoV3.22 (A3), DaisyChain2.2, R10kA3.2
ARDUINO_IN1: 74HC595.12 (RCLK), ArduinoNanoV3.6 (D3), DaisyChain1.1, J2.1
ARDUINO_IN2: 74HC595.11 (SRCLK), ArduinoNanoV3.7 (D4), DaisyChain1.2, J2.2
ARDUINO_IN3: 74HC595.14 (SER), ArduinoNanoV3.8 (D5), DaisyChain1.3, J2.3
ARDUINO_IN4: ArduinoNanoV3.9 (D6), J2.4
ARDUINO_IN5: ArduinoNanoV3.10 (D7), J2.5
ARDUINO_IN6: ArduinoNanoV3.11 (D8), J2.6
ARDUINO_OUTPUT_ENABLE: 74HC595.13 (~OE), ArduinoNanoV3.5 (D2), D9-D2.1, DaisyChain2.1, R10kD2.1
COB_K1: IRFZ44N#1.2 (D), J4.12
COB_K2: IRFZ44N#2.2 (D), J4.10
COB_K3: IRFZ44N#3.2 (D), J4.8
COB_K4: IRFZ44N#4.2 (D), J4.6
COB_K5: IRFZ44N#5.2 (D), J4.4
COB_K6: IRFZ44N#6.2 (D), J4.2
COB_K7: ExGND1.1, IRFZ44N#7.2 (D)
COB_K8: ExGND1.2, IRFZ44N#8.2 (D)
D9: ArduinoNanoV3.12 (D9), D9-D2.2, D9P1.1, Ethernet1.1
D10: ArduinoNanoV3.13 (D10), Ethernet1.3
D11: ArduinoNanoV3.14 (D11), Ethernet1.5
D12: ArduinoNanoV3.15 (D12), Ethernet1.4
D13: ArduinoNanoV3.16 (D13), Ethernet1.6
GND: 25V1000μF1.2, 25V1000μF2.2, 74HC595.8 (GND), -1.1, -1.2, ArdOk1.1, ArdVIN/GND1.2, ArduinoNanoV3.4 (GND), ArduinoNanoV3.29 (GND), BTN1.2, BTN2.2, C100nF1.1, EthGND1.1, GND1.1, GND1.2, GndT1.1, GndT2.1, I2C1.2, IRFZ44N#1.3 (S), IRFZ44N#2.3 (S), IRFZ44N#3.3 (S), IRFZ44N#4.3 (S), IRFZ44N#5.3 (S), IRFZ44N#6.3 (S), IRFZ44N#7.3 (S), IRFZ44N#8.3 (S), J1.2, J2.8, J3.8, PwrOk1.1, R10k1.2, R10k2.2, R10k3.2, R10k4.2, R10k5.2, R10k6.2, R10k7.2, R10k8.2, R10kA3.1, ToF#1.2, ToF#2.2, ToF#3.2
unnamed: 74HC595.9 (QH'), 'Q7.1
unnamed: ArdOk1.2, R220.2
unnamed: ArduinoNanoV3.19 (A0), ToF#1.5
unnamed: ArduinoNanoV3.20 (A1), ToF#2.5
unnamed: ArduinoNanoV3.21 (A2), ToF#3.5
unnamed: ArduinoNanoV3.23 (A4), I2C1.4, ToF#1.4, ToF#2.4, ToF#3.4
unnamed: ArduinoNanoV3.24 (A5), I2C1.3, ToF#1.3, ToF#2.3, ToF#3.3
unnamed: ArduinoNanoV3.25 (A6), BTN2.1, R10kA6.1
unnamed: ArduinoNanoV3.26 (A7), BTN1.1, R10kA7.1
unnamed: ArduinoNanoV3.2 (D0/RX), RX/TX1.1
unnamed: ArduinoNanoV3.1 (D1/TX), RX/TX1.2
unnamed: ArduinoNanoV3.3 (~RESET), RST1.1
unnamed: PwrOk1.2, R220Ohm1.2
VIN: ArdVIN/GND1.1, ArduinoNanoV3.30 (VIN)

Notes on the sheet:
Exposed headers to other peripherals
VIN GND SCL SDA XSHUT
Expose a header that directly connects to the arduino
LED Voltage can be anything that can be handled by the MOSFETS For the Magician lights 3.3V 1000mA is the rated input voltage which is way below the IRFZ44N specs
Expose a header that can daisy chain connect to another 74HC595 to extend outputs
Ground Sharing
Expose free arduino pins (when not using 74HC595) as 2x Digital I/O
2 Status LEDs
SRCLR can either be permanently 5V or controlled by arduino to prevent floating output during bootup
This is the place where the GND of Arduino touches the GND of the LED power supply
SDA is A4 SCL is A5

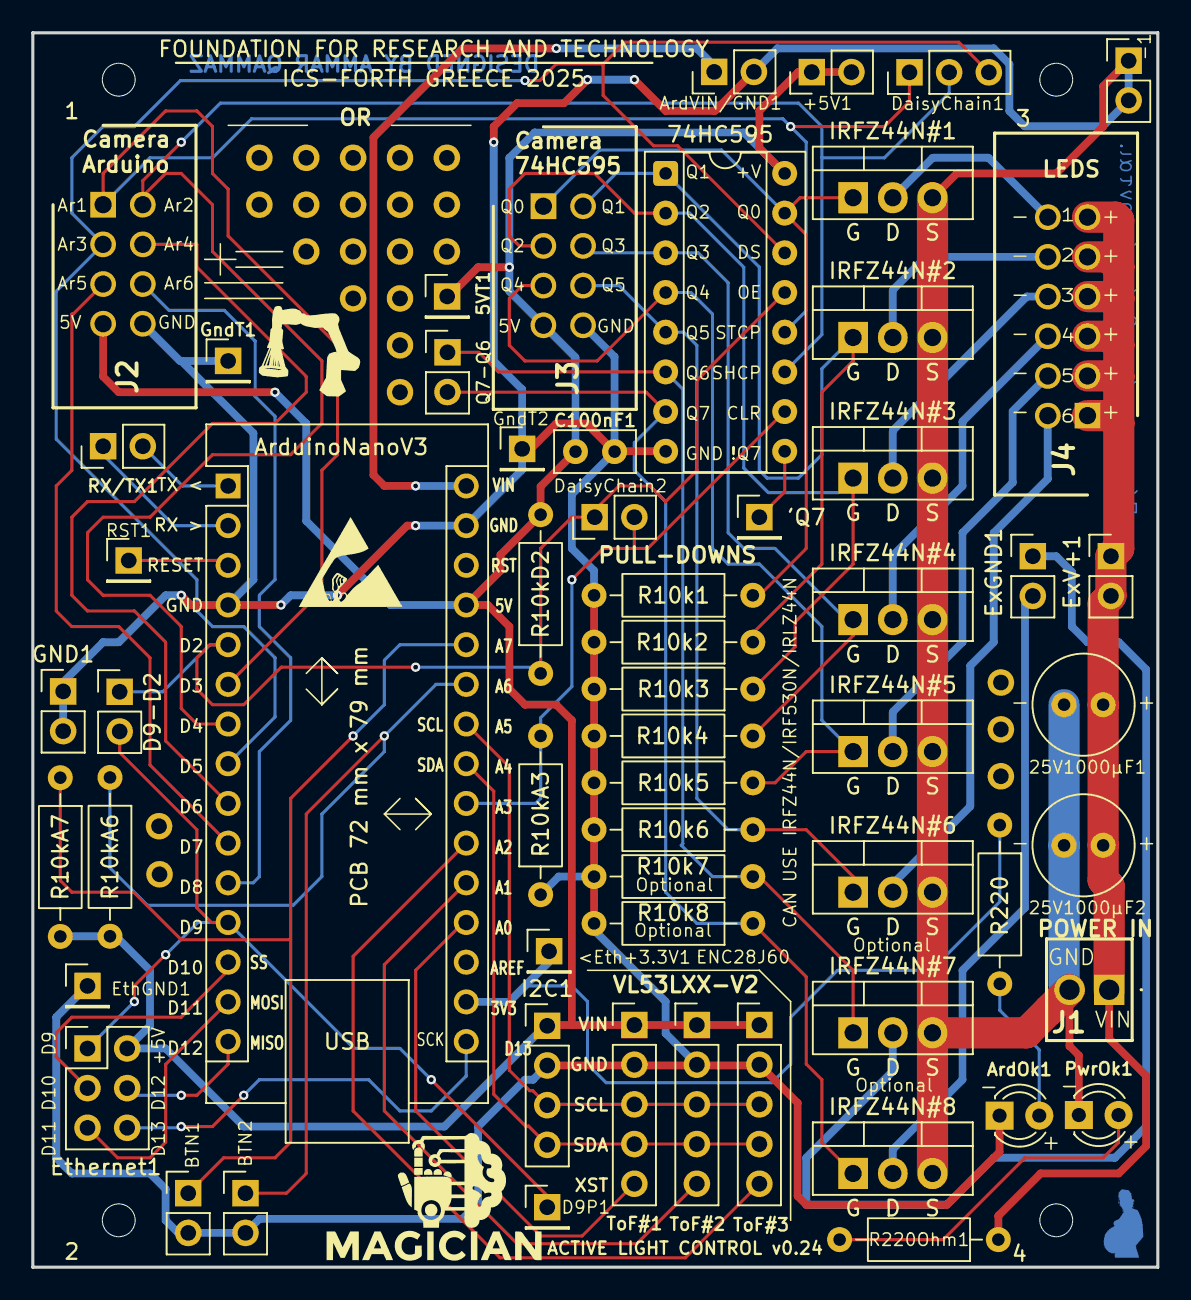
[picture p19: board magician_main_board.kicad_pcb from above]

Board: 2 copper layers, 72.0 x 79.0 mm, 63 parts (0 on the bottom side), 47 nets.

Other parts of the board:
1, 2, 3, 4: MountingHole_2.1mm

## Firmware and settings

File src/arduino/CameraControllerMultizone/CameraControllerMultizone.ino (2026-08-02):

// =============================================================================
//  CameraControllerMultizone — Raspberry Pi Pico 2 (RP2350)
//
//  Hardware summary
//  ─────────────────────────────────────────────────────────────────────────
//  I²C bus (GP4 SDA / GP5 SCL)
//    · 3× VL53L5CX  time-of-flight sensors  (datasheet 8-bit addr 0x52; Wire 7-bit addr 0x29 = 0x52 >> 1)
//      Each sensor is XSHUT-gated via MCP23018 GPA3/4/5 and reassigned a
//      unique address (0x30, 0x31, 0x32) during init.
//    · MCP23018 I²C port expander            (7-bit addr 0x20)
//
//  SPI0 bus — W5500 ethernet (USR-ES1 module)
//    MISO=GP16  MOSI=GP19  SCLK=GP18  CS=GP17  INT=GP22
//    Reset is driven by MCP23018 GPA2 (open-drain, active-low).
//
//  Direct GPIO
//    GP2  — XCG-CP510 camera exposure signal (active-high input)
//    GP3  — MCP23018 hardware reset (active-low output)
//    GP6  — Light 1
//    GP7  — Light 2
//    GP8  — Light 3
//    GP9  — Light 4
//    GP10 — Light 5
//    GP11 — Light 6
//    GP20 — MCP23018 INTA (open-drain, active-low, input with pull-up)
//    GP21 — MCP23018 INTB (open-drain, active-low, input with pull-up)
//    GP22 — W5500 INT     (active-low, input with pull-up)
//
//  MCP23018 Port A
//    GPA0 — Push Button 0  (input,  internal pull-up, active-low)
//    GPA1 — Push Button 1  (input,  internal pull-up, active-low)
//    GPA2 — W5500 RST      (output, open-drain, active-low)
//    GPA3 — XSHUT sensor 0 (output, open-drain, active-low)
//    GPA4 — XSHUT sensor 1 (output, open-drain, active-low)
//    GPA5 — XSHUT sensor 2 (output, open-drain, active-low)
//    GPA6 — 5 V  rail enable  (output, open-drain, ext pull-up)
//    GPA7 — 11.5 V rail enable(output, open-drain, ext pull-up)
//
//  MCP23018 Port B — all pins unconnected (inputs, internal pull-ups enabled)
//
//  NOTE: MCP23018 GPIO outputs are open-drain.  All output lines that must
//        reach a HIGH state require external pull-up resistors.
// =============================================================================

#include <Arduino.h>
#include <Wire.h>
#include <SPI.h>
#include <Ethernet.h>
#include <SparkFun_VL53L5CX_Library.h>
// Library: "SparkFun VL53L5CX Arduino Library" — install via Library Manager
#include "pico/time.h"      // add_alarm_in_us, cancel_alarm
#include "hardware/gpio.h"  // gpio_put, gpio_set_irq_enabled
#include "hardware/irq.h"   // irq_set_priority, PICO_HIGHEST_IRQ_PRIORITY

// =============================================================================
//  Feature flags
// =============================================================================
#define USE_LASER                  1   // Enable VL53L5CX time-of-flight sensors
#define USE_ETHERNET               1   // Enable W5500 ethernet
#define USE_MCP23018               1   // Enable MCP23018 I²C port expander
#define ENABLE_LASER_LIGHT_DECISION 1  // Enable depth-based automatic light selection
#define DEBUG_TOF               1   // Verbose ToF sensor init/scan output
#define DEBUG_ETHERNET             0   // Verbose ethernet init output

// =============================================================================
//  Version
// =============================================================================
#define VERSION_MAJOR 1
#define VERSION_MINOR 0

// =============================================================================
//  Debug macros
// =============================================================================
#if DEBUG_TOF
  #define DBG_TOF(...)   Serial.print(__VA_ARGS__)
  #define DBG_TOFLN(...) Serial.println(__VA_ARGS__)
#else
  #define DBG_TOF(...)
  #define DBG_TOFLN(...)
#endif

// =============================================================================
//  I²C bus
// =============================================================================
#define SDA_PIN 4   // GP4
#define SCL_PIN 5   // GP5

// =============================================================================
//  MCP23018 I²C port expander
// =============================================================================
#define MCP23018_ADDR      0x20  // 7-bit address; hardware pins A2=A1=A0=GND
#define MCP23018_RESET_PIN 3     // GP3  — active-low hardware reset
#define MCP23018_INTA_PIN  20    // GP20 — open-drain interrupt A (buttons)
#define MCP23018_INTB_PIN  21    // GP21 — open-drain interrupt B (unused)

// MCP23018 register addresses — IOCON.BANK=0 (sequential / paired layout, power-on default)
#define MCP23018_IODIRA   0x00  // Port A I/O direction  (1=input, 0=output)
#define MCP23018_IODIRB   0x01  // Port B I/O direction
#define MCP23018_IPOLA    0x02  // Port A input polarity
#define MCP23018_IPOLB    0x03  // Port B input polarity
#define MCP23018_GPINTENA 0x04  // Port A interrupt-on-change enable
#define MCP23018_GPINTENB 0x05  // Port B interrupt-on-change enable
#define MCP23018_DEFVALA  0x06  // Port A default compare value for interrupts
#define MCP23018_DEFVALB  0x07  // Port B default compare value
#define MCP23018_INTCONA  0x08  // Port A interrupt control (0=vs prev, 1=vs DEFVAL)
#define MCP23018_INTCONB  0x09  // Port B interrupt control
#define MCP23018_IOCON    0x0A  // Chip configuration register
#define MCP23018_GPPUA    0x0C  // Port A pull-up enable (input pins only)
#define MCP23018_GPPUB    0x0D  // Port B pull-up enable
#define MCP23018_INTFA    0x0E  // Port A interrupt flag  (read-only)
#define MCP23018_INTFB    0x0F  // Port B interrupt flag  (read-only)
#define MCP23018_INTCAPA  0x10  // Port A value captured at interrupt (read-only)
#define MCP23018_INTCAPB  0x11  // Port B value captured at interrupt (read-only)
#define MCP23018_GPIOA    0x12  // Port A GPIO register   (read = pin state)
#define MCP23018_GPIOB    0x13  // Port B GPIO register
#define MCP23018_OLATA    0x14  // Port A output latch    (write = set outputs)
#define MCP23018_OLATB    0x15  // Port B output latch

// Port A bit positions (used with mcp23018SetPortABit / read helpers)
#define MCP_GPA_PB0     0   // Push Button 0     — input,  pull-up (LOW=pressed)
#define MCP_GPA_PB1     1   // Push Button 1     — input,  pull-up (LOW=pressed)
#define MCP_GPA_ETHRST  2   // W5500 Reset       — output, open-drain, active-low
#define MCP_GPA_XSHUT0  3   // ToF XSHUT 0       — output, open-drain, active-low
#define MCP_GPA_XSHUT1  4   // ToF XSHUT 1       — output, open-drain, active-low
#define MCP_GPA_XSHUT2  5   // ToF XSHUT 2       — output, open-drain, active-low
#define MCP_GPA_RAIL5V  6   // 5 V  rail enable  — output, open-drain, ext pull-up
#define MCP_GPA_RAIL11V 7   // 11.5 V rail enable— output, open-drain, ext pull-up

// =============================================================================
//  VL53L5CX time-of-flight sensors
// =============================================================================
#define NUMBER_OF_DISTANCE_SENSORS 3

// Unique 7-bit I²C addresses assigned to each sensor after reset sequencing.
// The VL53L5CX datasheet quotes the default I²C address as 0x52 in 8-bit notation.
// The Arduino Wire library uses 7-bit addresses: 0x52 >> 1 = 0x29.  The value 0x29
// passed to tof[i].begin() is therefore correct for the Wire API.
// After sequencing, all three sensors are reassigned unique 7-bit addresses.
#define LOX1_ADDRESS 0x30
#define LOX2_ADDRESS 0x31
#define LOX3_ADDRESS 0x32
const uint8_t LOX_ADDRESS[NUMBER_OF_DISTANCE_SENSORS] = {LOX1_ADDRESS, LOX2_ADDRESS, LOX3_ADDRESS};

#define XSHUT_BOOT_DELAY_MS  80  // Time to allow a sensor to boot after XSHUT goes HIGH
#define XSHUT_RESET_DELAY_MS 10  // Time to hold all sensors in reset before sequencing

// =============================================================================
//  Light control
// =============================================================================
#define NUMBER_OF_LIGHTS 6
#define NO_LIGHT_ON      16  // Sentinel — no light currently active

// Direct GPIO pins for lights 1–6 (GP6–GP11)
const uint8_t directLightControl[NUMBER_OF_LIGHTS] = {6, 7, 8, 9, 10, 11};

// =============================================================================
//  Camera exposure trigger — XCG-CP510
// =============================================================================
// GP2 goes HIGH during the camera shutter open window (active-high).
// The sketch turns the currently selected light on at the rising edge and off
// at the falling edge so illumination is perfectly gated to exposure time.
#define CAMERA_EXPOSURE_PIN 2

// =============================================================================
//  Ethernet — W5500 (USR-ES1 module)
// =============================================================================
// SPI0: MISO=GP16, MOSI=GP19, SCLK=GP18, CS=GP17, INT=GP22
// Hardware reset is managed by MCP23018 GPA2 — no dedicated Pico reset pin.
#define ETHERNET_CS_PIN  17   // GP17
#define ETHERNET_INT_PIN 22   // GP22, active-low interrupt from W5500

// Network configuration — adjust to suit your deployment


byte     mac[]     = {0x02, 0xAB, 0xCD, 0x12, 0x34, 0x56};

//Laptop IP should be something like : 169.254.153.1
//SONY Camera IP should be something like : 169.254.143.109
//Let's make this device compatible with all of these!
IPAddress ip(169, 254, 143, 23);
byte     gateway[] = {169, 254, 143, 1};
byte    *dns       = gateway;
byte     subnet[]  = {255, 255, 0, 0};

EthernetServer server(23);   // Telnet-style command server on port 23
EthernetClient client;

// =============================================================================
//  Global state
// =============================================================================
#define CPU_SLEEP_US 1000   // Microseconds to sleep at the end of each loop tick

bool         serialOutputEnabled  = false;
unsigned int loopRateMsec         = 10;   // Main loop cadence (10 ms = 100 Hz)
unsigned int lightDurationMsec    = 100;  // How long each light stays on in auto modes

// Exposure-ISR timing parameters — written only by the command handler, read by ISRs.
// All times are measured from the rising edge of the camera exposure signal (t = 0).
volatile uint32_t LightDebouncingMicroseconds = 0;  // µs: delay before arming falling-edge ISR (set in setup)
volatile uint32_t lightTurnOffMicroseconds    = 0;  // µs: maximum light-on window from rising edge (set in setup)
volatile uint32_t LightKeepOffMicroseconds    = 0;  // µs: guard-rail before rising-edge ISR re-arms (set in setup)

// lightToActivate: 0 = no light, 1–6 = light to illuminate on next exposure rising edge.
// Written by activateLight() / deactivateLights() in the main context; read in exposureISR().
volatile uint8_t lightToActivate = 0;

unsigned char autoLights = 0;           // 0=manual 1=sequential 2=depth-guided 3=alt-seq 4=timed-seq
unsigned char lightOn    = NO_LIGHT_ON; // Logically selected light index, 0-indexed (NO_LIGHT_ON=none)

unsigned long lastUpdateTime = 0;
unsigned long lightStartTime = 0;

// =============================================================================
//  VL53L5CX sensor objects
// =============================================================================
SparkFun_VL53L5CX  tof[NUMBER_OF_DISTANCE_SENSORS];
VL53L5CX_ResultsData tofResults;  // Single results buffer, reused across all sensors

uint8_t  laser_working[NUMBER_OF_DISTANCE_SENSORS] = {0};   // 1 if sensor initialised OK
uint8_t  laser_status [NUMBER_OF_DISTANCE_SENSORS] = {0};   // 1 if new data available this tick
uint16_t laser_distance_millimeters[NUMBER_OF_DISTANCE_SENSORS] = {0};

// Full 8×8 (64-zone) distance frame for each sensor, refreshed every time
// read_triple_sensors() pulls a new frame.  Streamed verbatim by reportZones().
uint16_t zoneDistances[NUMBER_OF_DISTANCE_SENSORS][64] = {0};
// Per-sensor "fresh frame captured but not yet transmitted" flag.  Set when
// read_triple_sensors() pulls a new frame, cleared by reportZones() once it is
// sent — so each ToF frame is written to disk exactly once even when the report
// rate (camera frame rate, up to 23 Hz) exceeds the 15 Hz sensor ranging rate.
uint8_t zoneFrameFresh[NUMBER_OF_DISTANCE_SENSORS] = {0};
// When set, every reportState() line is followed by three "x1/x2/x3" zone lines.
// Defaults ON: this firmware only runs on the multizone (VL53L5CX) hardware.
bool emitAllZones = true;

// =============================================================================
//  MCP23018 state
// =============================================================================
static bool    mcp23018_present    = false;
static uint8_t mcp23018_portA_latch = 0xFC;  // Software mirror of OLATA — avoids an extra I²C read
                                              // on every bit-set operation

// =============================================================================
//  Utilities
// =============================================================================

// reset_millis — zero the millisecond counter so timestamps in the serial
// output start from 0 whenever a new capture session begins.
// reset_millis stores a snapshot of millis() so that currentTime in each new
// capture session starts near zero (the command handler sets currentTime=0 on
// the same tick, making the timestamps consistent from the host's perspective).
static uint32_t millis_offset = 0;
void reset_millis() { millis_offset = millis(); }

// Software reset — jumps to address 0; works reliably on RP2040 (maps to ROM).
void (* resetFunc)(void) = 0;

// freeRAM — returns approximate free heap bytes (informational only).
int freeRAM()
{
#if defined(ARDUINO_ARCH_RP2040)
  return 512000;  // RP2350 has 520 kB SRAM; report a conservative constant
#else
  return -1;
#endif
}

void version()
{
  Serial.print(F("V:")); Serial.print(VERSION_MAJOR);
  Serial.print(F(".")); Serial.println(VERSION_MINOR);
#if USE_ETHERNET
  if (client) {
    client.print(F("V:")); client.print(VERSION_MAJOR);
    client.print(F(".")); client.println(VERSION_MINOR);
  }
#endif
}

void sram()
{
  Serial.print(F("SRAM(")); Serial.print(freeRAM()); Serial.println(F("b free)"));
}

// =============================================================================
//  I²C scan — checks only the known-present addresses (DEBUG_TOF only)
//
//  Expected addresses in this system:
//    0x20 — MCP23018 port expander (fixed, always present)
//    0x29 — VL53L5CX default boot address (7-bit of datasheet 8-bit 0x52)
//    0x30, 0x31, 0x32 — VL53L5CX after address reassignment
//  Scanning only these five addresses avoids probing the full 127-address space
//  and keeps initialisation time short at the 1 MHz (FM+) bus speed.
// =============================================================================
#if DEBUG_TOF
static void scanI2C()
{
  static const uint8_t known[] = {0x20, 0x29, 0x30, 0x31, 0x32};
  DBG_TOFLN(F("I2C scan:"));
  uint8_t count = 0;
  for (uint8_t k = 0; k < sizeof(known); k++)
  {
    uint8_t addr = known[k];
    Wire.beginTransmission(addr);
    if (Wire.endTransmission() == 0)
    {
      DBG_TOF(F("  found @ 0x"));
      if (addr < 16) DBG_TOF('0');
      DBG_TOFLN(addr, HEX);
      count++;
    }
  }
  if (count == 0) DBG_TOFLN(F("  (none)"));
}
#else
static void scanI2C() {}
#endif
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
void loop()
{
  unsigned long currentTime = millis();

  // Light activation and deactivation are fully handled by exposureISR() and its
  // timer callbacks (lightOffCallback / guardRailCallback).  The main loop only
  // updates lightToActivate via activateLight() / deactivateLights().

  // ── Button read via MCP23018 ──────────────────────────────────────────────────
  // GPA0/GPA1 use internal pull-ups; a button press pulls the pin LOW.
  // We read the whole Port A GPIO register in a single I²C transaction and
  // extract the two button bits.  1 = pressed, 0 = not pressed.
  uint8_t mcpGpioA = mcp23018_present ? mcp23018ReadReg(MCP23018_GPIOA) : 0xFF;
  unsigned int buttonRaw1 = (mcpGpioA & (1u << MCP_GPA_PB0)) ? 0 : 1;
  unsigned int buttonRaw2 = (mcpGpioA & (1u << MCP_GPA_PB1)) ? 0 : 1;

  // ── Ethernet client management ───────────────────────────────────────────────
  char receivedChar = 0;
#if USE_ETHERNET
  // Drop stale connections (client disconnected without sending FIN)
  if (client && !client.connected())
  {
    client.stop();
    client = EthernetClient();
  }
  // Accept a new client if no one is connected
  if (!client)
  {
    EthernetClient nc = server.available();
    if (nc) { client = nc; client.flush(); Serial.println(F("ETH: client connected")); }
  }
  // Read one command byte from the Ethernet client if available
  if (client && client.available() > 0) receivedChar = client.read();
#endif

  // Read one command byte from the USB serial port if available.
  // If both serial and ethernet produce a byte in the same tick, serial wins
  // (it overwrites receivedChar) — acceptable since commands are rare.
  if (Serial.available() > 0) receivedChar = Serial.read();

  // ── Command handler ───────────────────────────────────────────────────────────
  // Single-character protocol over serial or telnet:
  //   v        — print firmware version
  //   h / i    — reset timer, enable output, start sequential light cycling
  //   0        — all lights off, stop auto cycle
  //   1–6      — activate specific light (manual mode)
  //   r        — sequential mode from light 0
  //   a        — depth-guided auto mode (uses ToF readings)
  //   t        — alternating-pair mode from light 0
  //   y        — timed flash mode (cycles for 10 s then stops)
  //   +        — advance one light step (manual stepping)
  //   o        — reset maximum light-on time to default (1000 µs)
  //   p        — extend maximum light-on time by 500 µs
  //   f        — disable serial output stream
  //   z        — all off + software reset
  //   x        — print Ethernet IP and hardware status
  if (receivedChar != 0)
  {
    switch (receivedChar)
    {
      case 'v': version(); break;

      case 'h':
      case 'i':
        reset_millis();
        serialOutputEnabled = true;
        currentTime         = 0;
        lightStartTime      = 0;
        autoLights          = 1;
        lightOn             = 0;
        lightToActivate     = 0;  // auto-cycle will set this on the first tick
        break;

      case '0': deactivateLights(); autoLights = 0;                    break;
      case '1': activateLight(0);   autoLights = 0;                    break;
      case '2': activateLight(1);   autoLights = 0;                    break;
      case '3': activateLight(2);   autoLights = 0;                    break;
      case '4': activateLight(3);   autoLights = 0;                    break;
      case '5': activateLight(4);   autoLights = 0;                    break;
      case '6': activateLight(5);   autoLights = 0;                    break;

      case 'r': autoLights = 1; lightOn = 0;                           break;
      case 'a': autoLights = 2;                                        break;
      case 't': autoLights = 3; lightOn = 0;                           break;
      case 'y': autoLights = 4; lightOn = 0;                           break;

      case 'o': lightTurnOffMicroseconds  = 1000;  break;  // reset to default max light-on time
      case 'p': lightTurnOffMicroseconds += 500;  break;  // extend max light-on time

      case 'm': emitAllZones = true;  break;  // stream full 8×8 zone frames (x1/x2/x3 lines)
      case 'c': emitAllZones = false; break;  // compact only — suppress zone frames

      case 'f': serialOutputEnabled = false;           break;
      case 'z': deactivateLights(); autoLights = 0; resetFunc(); break;

      case '+':
        autoLights = 0;
        lightOn    = getNextLight(lightOn, NUMBER_OF_LIGHTS, autoLights);
        activateLight(lightOn);
        lightStartTime = currentTime;
        reportState(currentTime, buttonRaw1, buttonRaw2);
        if (emitAllZones) reportZones(currentTime);
        break;

#if USE_ETHERNET
      case 'x':
        Serial.print(F("ETH IP: ")); Serial.println(Ethernet.localIP());
        Serial.print(F("ETH HW: ")); Serial.println(Ethernet.hardwareStatus());
        sram();
        break;
#endif
    }
  }

  // ── Timed main loop ───────────────────────────────────────────────────────────
  // Everything below runs at the loopRateMsec cadence (default 10 ms = 100 Hz).
  if (currentTime - lastUpdateTime >= loopRateMsec)
  {
    lastUpdateTime = currentTime;

    // Poll all ToF sensors for new distance data
#if USE_LASER
    read_triple_sensors();
#endif

    // Automatic light cycling and periodic state reporting
    if (autoLights != 0 && (currentTime - lightStartTime >= lightDurationMsec))
    {
      lightStartTime = currentTime;

      if (autoLights == 1 || autoLights >= 3)
      {
        lightOn = getNextLight(lightOn, NUMBER_OF_LIGHTS, autoLights);
        activateLight(lightOn);
        // Mode 4: timed flash — cycle for 10 s then stop automatically
        if (autoLights == 4 && currentTime > 10000)
        {
          autoLights = 0;
          deactivateLights();
        }
      }
#if ENABLE_LASER_LIGHT_DECISION
      else if (autoLights == 2)
      {
        lightOn = chooseClosestLight(laser_distance_millimeters);
        activateLight(lightOn);
      }
#endif

      if (serialOutputEnabled)
      {
        reportState(currentTime, buttonRaw1, buttonRaw2);
        if (emitAllZones) reportZones(currentTime);
      }
    }
  }

  // ── Yield / sleep ─────────────────────────────────────────────────────────────
  // Brief pause to avoid hammering the I²C bus and the W5500.
  // Strobe timing is now ISR-driven, so no compensation is needed here.
  // The exposure ISR can preempt this delay at any time.
  delayMicroseconds(CPU_SLEEP_US);
}

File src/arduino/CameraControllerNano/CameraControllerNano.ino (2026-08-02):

#include <Arduino.h> //<- this should be first to make sure all includes are ok
#include <Wire.h>

#include "VL53L0X.h"
//  git clone https://github.com/pololu/vl53l0x-arduino && cp vl53l0x-arduino/VL53L0X.cpp ./ && cp vl53l0x-arduino/VL53L0X.h ./ 


#define USE_ARDUINO_NANO 1

#define USE_LASER 1
#define DEBUG_LASERS 0
#define ENABLE_LASER_LIGHT_DECISION 1

//Expecting a W5100 ethernet 
#define USE_ETHERNET 1
#define DEBUG_ETHERNET 0

// =============================================================================
//  ALLOW_ALWAYS_ON_LIGHTS - LED SAFETY GATE
//
//  0 (default) - a light can never be driven for longer than
//                LIGHT_TURNOFF_US_MAX in one go. 'o' restores that bounded
//                default instead of removing the limit, 'p' is clamped to it, and
//                lightTurnOffMicrosecond can never be set to 0.
//
//  1           - historical Nano behaviour: lightTurnOffMicrosecond starts at 0
//                and 'o' returns it to 0, meaning each light stays on
//                CONTINUOUSLY until the next light change (~lightDurationMsec,
//                i.e. ~100 ms, roughly 17% duty per LED).
//
//  Set to 1 ONLY for the original Nano rig, whose IRFZ44N low-side switches drive
//  LEDs at their rated voltage and tolerate continuous drive. Leave it at 0 for
//  any board carrying the overvolted COBs used on MagicianCam4 - those survive
//  only because they are strobed, and ~17% duty destroys them.
//
//  !! FUNCTIONAL CONSEQUENCE OF THE DEFAULT !!
//  This board has NO camera exposure input, so a bounded pulse is not
//  synchronised to the shutter: the light fires when the command is processed,
//  not when the sensor is integrating. With ALLOW_ALWAYS_ON_LIGHTS at 0 the
//  frames will therefore be dark or partially lit. The safe default is safe, not
//  useful for capture - if this rig is being used to record with normal LEDs, set
//  it to 1 deliberately. Exposure-gated strobing needs the MagicianCam4 hardware.
// =============================================================================
#define ALLOW_ALWAYS_ON_LIGHTS 0

// Maximum microseconds a single light may be driven when the gate above is 0.
// Matches LIGHT_HARD_MAX_ON_US in MagicianCam4 Rev 1.33.
#define LIGHT_TURNOFF_US_MAX 1000

#define NUMBER_OF_LIGHTS 6
#define NUMBER_OF_DISTANCE_SENSORS 3

// =============================================================================
//  VERSION NUMBERING - LOAD-BEARING, DO NOT BUMP THE MAJOR
//
//  The host (magician_grabber) decides which command set a board can be given by
//  parsing this banner. Its rule is:
//
//      exposure-locked capable  <=>  major > 1 || (major == 1 && minor >= 33)
//
//  The Nano line is permanently reserved to 0.x and must never exceed 0.99, which
//  is what keeps it on the legacy command path. This is not cosmetic: the newer
//  commands are multi-character ('S031425'), and a board that consumes one byte
//  per command would execute their individual characters as separate legacy
//  commands -- '0' is ALL LIGHTS OFF and '3' selects light 3. Announcing 1.x here
//  would make the host scramble this board rather than simply not use the feature.
//
//  The Pico 2 / MagicianCam4 line owns 1.x and above.
// =============================================================================
#define VERSION_MAJOR 0
#define VERSION_MINOR 29

// I2C communication
#define SDA_PIN A4
#define SCL_PIN A5
#define I2C_EXTRA_PIN 9
#define ETHERNET_RESET_PIN 9

// 74HC595 control pins
uint8_t use74HC595ForLightControl = 0;  // By default start in direct pin mode
#define LATCH_PIN 3          // STCP
#define CLOCK_PIN 4          // SHCP
#define DATA_PIN  5          // DS
#define OUTPUT_ENABLE_PIN 2  // OUTPUT ENABLE / OE
#define CLEAR_PIN A3         // CLEAR / SRCLR

#define NO_LIGHT_ON 16

//Arduino Nano/UNO Port
//The laser library is so big that it may cause a stack overflow (running out of memory and over the heap)
//Causing the arduino to restart cycle. To fix this a special version of "Ammar_VL53L0X" strips a lot of fat
//*AND* there needs to be a change in the TX/RX buffer sizes by
// Altering : ~/.arduino15/packages/arduino/hardware/avr/1.8.6/cores/arduino/HardwareSerial.h
// changing SERIAL_TX_BUFFER_SIZE to 16 and SERIAL_RX_BUFFER_SIZE to 8
//With this trick :
//Sketch uses 20460 bytes (66%) of program storage space. Maximum is 30720 bytes.
//Global variables use 1647 bytes (80%) of dynamic memory, leaving 401 bytes for local variables. Maximum is 2048 bytes.
//--------------------------------------------------
#if USE_ARDUINO_NANO
const unsigned char directLightControl[NUMBER_OF_LIGHTS]={3,4,5,6,7,8}; //The last port is 9 because 7 doesn't work for some reason :S
#define annotationButton A7 
#define secondButton     A6
const unsigned char laserSwitch[NUMBER_OF_DISTANCE_SENSORS]={A0,A1,A2}; //Ports of XSHUT triggers
#endif
//--------------------------------------------------

//#define USE_LASER_1 1
//#define USE_LASER_2 1
//#define USE_LASER_3 1
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

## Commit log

2025-08-28 Add Arduino Nano Source code (0.26)
2025-08-28 add Kicad 9.0 PCB blueprint
    [magician_main_board.kicad_pcb, magician_main_board.kicad_sch]
2025-08-28 add board
2025-08-29 add connectors
2025-09-24 added step file for main board
    [magician_main_board.step]
2026-06-16 make ethernet of board compatible with ethernet of camera..
2026-08-05 1.63: restore standard GP3/GP20 MCP23018 pins, vendor VL53L5CX lib patch
    The MCP23018 reset and INTA defines inherited from 1.6 were the Giovinazzo
    debug board's, where GP3 and GP20 are broken and Y-wired to GP1 and GP28
    behind the RPY socket. On a standard MagicianCam4 that leaves the expander
    unreset, so restore 3 and 20 and document the variant in the header.
    Also vendor the patched Adafruit_VL53L5CX 1.0.1 sources this firmware is
    built against, alongside the stock ones so the patch stays diffable after a
    library update. They add I2C retries in the platform layer plus retry paths
    around the 0x000F boot transition and the FW-access enable in vl53l5cx_init().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
    [MagicianCam4.ino, platform.cpp, vl53l5cx_api.cpp]
2026-08-08 Giulio's corrections on the claude code..
    [MagicianCam4.ino]
2026-08-25 initial commit of v4 board..
    [MagicianCam4.kicad_pcb, MagicianCam4.kicad_sch, magician_main_board.kicad_pcb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]
2026-11-13 also touch power rails..
